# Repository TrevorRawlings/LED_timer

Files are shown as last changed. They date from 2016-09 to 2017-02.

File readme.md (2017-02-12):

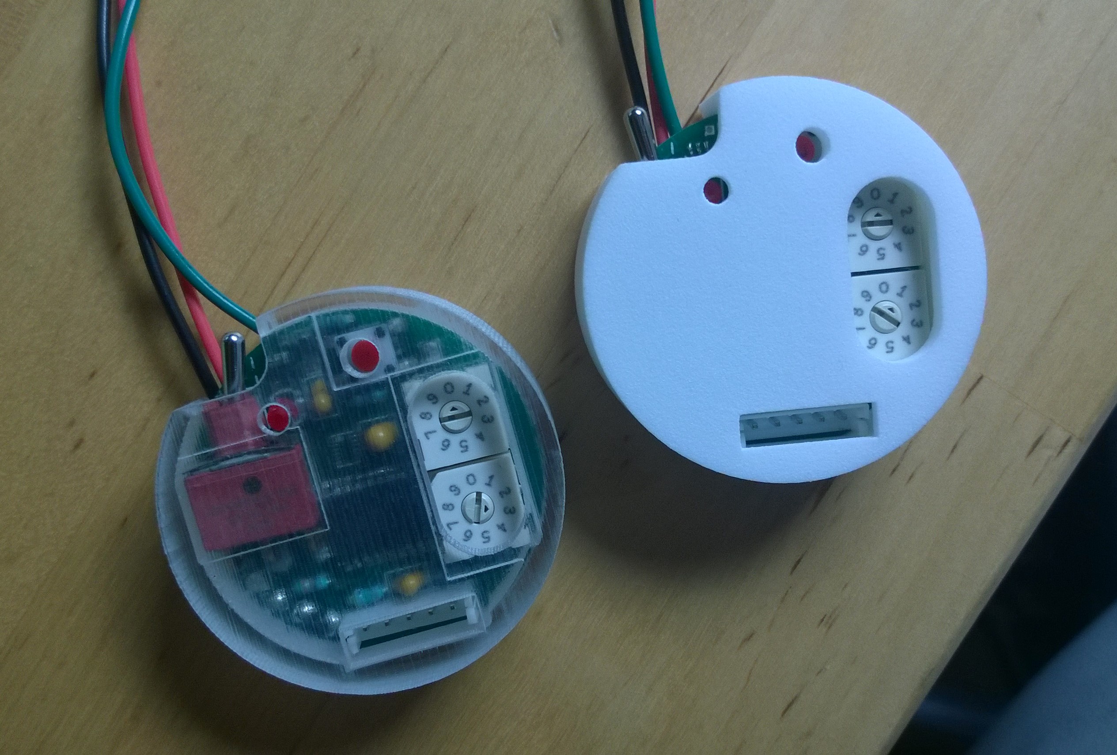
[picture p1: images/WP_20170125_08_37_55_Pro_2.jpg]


# Design Overview
## Mechanical

To fit within the waterproof housing the timer is limited to a 44mm diameter cylinder of height 15mm.

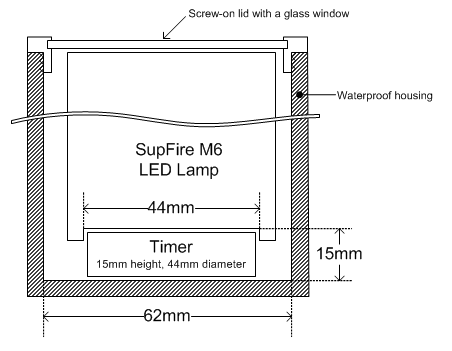
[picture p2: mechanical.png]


The case has been designed using [freeCad](https://www.freecadweb.org/). See the [Configuring FreeCad](#configuring-freecad) 
section below for help setting it up. 

The design files are in the `./freeCad` subdirectory and the finished designs have been 
uploaded to sculpteo ([sculpteo/case2-66](https://www.sculpteo.com/en/print/case2-66/AvhQv5jK) and [sculpteo/bottom-1007](https://www.sculpteo.com/en/print/bottom-1007/qzUkbDYg)).

## Electrical

The unit has a single 2 layer, 40mm diameter PCB.

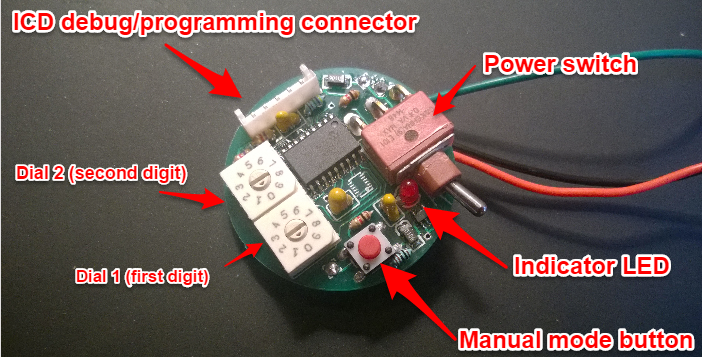
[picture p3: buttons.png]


The electrical design files are in the `./eagle` subfolder. The majority of the components have been sourced from [digiKey](http://www.digikey.com/). See [bill\_of\_materials.xlsx](bill_of_materials.xlsx) for details.

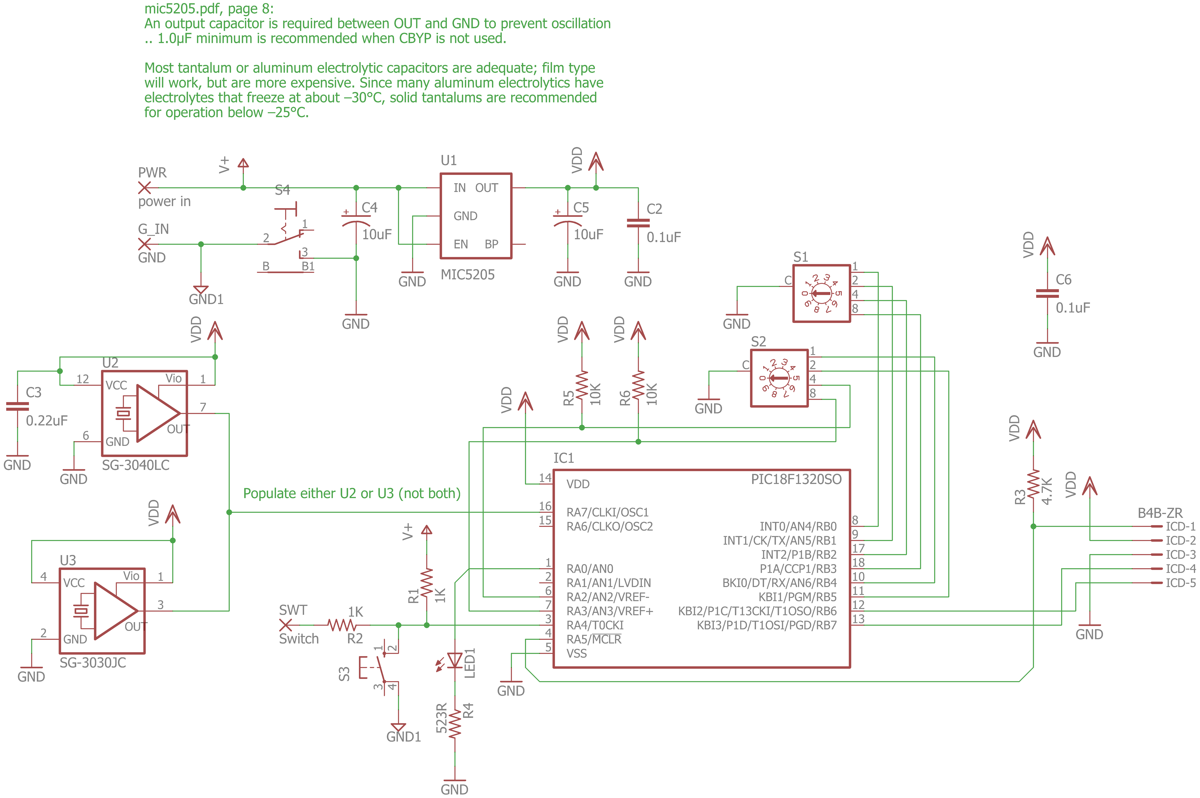
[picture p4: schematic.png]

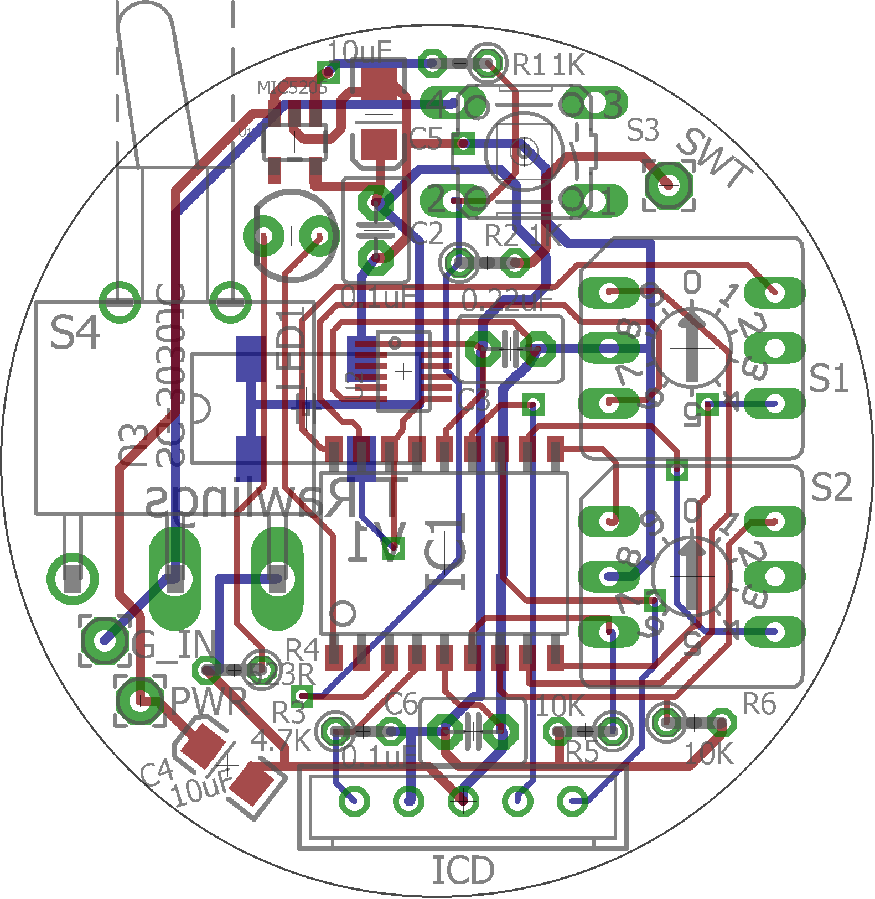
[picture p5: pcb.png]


### PCB Manufacture
The circuit boards have been manufactured using [PCBWay](http://www.pcbway.com/).  The steps required to gerber files required by PCBWay are documented in [a blog post](cam_processor/How to generate Gerber from Eagle-SOFTWARE - Share- Hacker - PCBWay.pdf)

TODO: Create a grunt task that automates the process.

Once the .zip archive containing the gerber files has been generated it needs to be uploaded to PCBWay.  The parameters used when submitting an order are [here](cam_processor/pcbway_order_parameters.pdf).

## Software

Software is in the `mplab\LED.X` subfolder.  

#Tools

1. [Cadsoft Eagle PCB Design](https://cadsoft.io/)

   To use the Grunt task the eagle binary will need to be in the [system path](http://www.computerhope.com/issues/ch000549.htm).  For me that meant adding `C:\EAGLE-7.6.0\bin` to the path.
   
1. [Microchip MPLAB X Integrated Development Envrionment (IDE)](http://www.microchip.com/mplab/mplab-x-ide)

1. [MPLAB ICD 3 In-Circuit Debugger](http://www.microchip.com/Developmenttools/ProductDetails.aspx?PartNO=DV164035)

1. [FreeCAD](http://www.freecadweb.org/)
1. [eaglepcb2freecad](https://sourceforge.net/projects/eaglepcb2freecad/?source=typ_redirect)

   A FreeCAD plugin that can import the PCB design from eagle and generate a 3D represenation of the PCB.
      1. Download the [FreeCAD plugin]( https://sourceforge.net/projects/eaglepcb2freecad/?source=typ_redirect)
      1. The .7zachive will need to be extracted. I used the linux tool [dtrx](https://brettcsmith.org/2007/dtrx/)
      1. Follow the instructions within the archive to install the plugin
	  1. eaglepcb2freecad's parts library will need to be configured.  See the [Configuring FreeCAD](#configuring-freecad) section below.

1. [Nodejs](https://nodejs.org/en/)
   Used to download the 3D CAD model libraries used by FreeCAD. 
   
   Download and run the installer. Then at the command prompt:
   ```
   npm install
   ```

2. [Grunt](http://gruntjs.com/getting-started#installing-the-cli)

   Used to automate some tasks.
   
   ```
   npm install -g grunt-cli
   ```

# Configuring FreeCAD

1. Configure eaglepcb2freecad. Open freeCAD and then from the top menu go Edit > Preferences.  In the window the opens select 'PCB' from the list on the left

  * Set the default board thickness to 1.6mm
  * Set the Parts:Paths to include the location of the [freecad_eagle_models](https://github.com/TrevorRawlings/freecad_eagle_models) and [electrical_components](https://github.com/TrevorRawlings/electrical_components) git repositories.  If you have run a `npm install` then two git repos will have been cloned into the node_modules subdirectory:
  
    <project_folder>\node_modules\electrical_components,
	<project_folder>\node_modules\freecad_eagle_models\models_1,
	<project_folder>\node_modules\freecad_eagle_models\models_2,
	<project_folder>\node_modules\freecad_eagle_models\models_3,
	<project_folder>\node_modules\freecad_eagle_models\models_4,
	
  * Import the parts database `eagle2FreecadPartsDb\freecad-pcb_copy.fpcb`
  
    Select 'Printed Circuit Board' `View > Workbench` menu and then click the Assign Models button on the PCB Settings tool bar (see the image below)
	
	
	
	In the window that openc click 'Import Database' from the menu on the left.
    	E:\projects\ALFA_LED\node_modules\electrical_components,E:\projects\ALFA_LED\node_modules\freecad_eagle_models\models_1,E:\projects\ALFA_LED\node_modules\freecad_eagle_models\models_2,E:\projects\ALFA_LED\node_modules\freecad_eagle_models\models_3,E:\projects\ALFA_LED\node_modules\freecad_eagle_models\models_4

	E:\freeCadModels\models_1,E:\freeCadModels\models_2,E:\freeCadModels\models_3,E:\freeCadModels\models_4,E:\freeCadModels\custom

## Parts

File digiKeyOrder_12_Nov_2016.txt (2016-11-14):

Index	Quantity	Part Number	Description	Customer Reference	Available Quantity	Backorder Quantity	Unit Price USD	Extended Price USD	
1	25	478-8275-1-ND	CAP TANT 10UF 20V 20% 1206	C4, C5	25	0	0.32440	8.11	
2	22	GH7252-ND	SWITCH ROTARY DIP BCD 100MA 50V	S1, S2	22	0	2.76200	60.76	
3	15	SER3697CT-ND	OSC XO 32.768KHZ CMOS SMD	U1	15	0	1.51400	22.71	
4	15	450-1804-ND	SWITCH TACTILE SPST-NO 0.05A 24V	S3	15	0	0.08600	1.29	
5	12	CKN1060-ND	SWITCH TOGGLE SPDT 0.4VA 20V	S4	12	0	4.98200	59.78	
6	50	RNF18FTD10K0CT-ND	RES 10K OHM 1/8W 1% AXIAL	ALT R3, R5, R6	50	0	0.03860	1.93	
7	50	RNF18FTD1K00CT-ND	RES 1K OHM 1/8W 1% AXIAL	R1, R2, R4	50	0	0.03860	1.93	
8	50	RNF18FTD4K75CT-ND	RES 4.75K OHM 1/8W 1% AXIAL	R3, R5, R6	50	0	0.03860	1.93	
9	15	576-1258-1-ND	IC REG LDO 3V 0.15A SOT23-5	U1	15	0	0.40000	6.00	
10	15	492-1785-ND	LED MT SELF RETAINING VERT		15	0	0.21400	3.21	
11	10	455-1614-ND	CONN HEADER EH TOP 5POS 2.5MM	ICD CONNECTOR	10	0	0.22300	2.23	
12	20	455-1042-1-ND	CONN TERM CRIMP EH 22-30AWG	ICD CONNECTOR	20	0	0.04900	0.98	
13	5	PIC18LF1320-I/SO-ND	IC MCU 8BIT 8KB FLASH 18SOIC	IC1	5	0	2.73000	13.65	
14	25	478-9315-ND	CAP TANT 0.1UF 50V 20% RADIAL	C2, C6	25	0	0.25200	6.30	
15	10	478-8818-ND	CAP TANT 0.22UF 50V 20% RADIAL	C3	10	0	0.29500	2.95	
16	10	TLLR4400-ND	LED RED DIFF 3.2MM ROUND T/H	LED1	10	0	0.35800	3.58	
17	10	SER3618CT-ND	OSC XO 32.768KHZ CMOS SMD	U3	10	0	1.46900	14.69	
18	50	RNF18FTD523RCT-ND	RES 523 OHM 1/8W 1% AXIAL	R4	50	0	0.03860	1.93	
						Subtotal	213.96
						Shipping	unknown
						Estimated Sales Tax	0.00
						Total	unknown

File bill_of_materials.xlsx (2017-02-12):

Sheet: Bill_of_materials
 |  | desc | manufacturer/part no | price | number per board | cost per board | source
 | RJ-11 | ICD debugger |  | 3.9 | 0 | 0 | digikey part number 553-2258-ND
 | JST-EH 5 pin | receptacle (housing) | EHR-5 | 0.1 | 0 |  | 455-1003-ND
 |  | socket |  | 0.24 | 1 |  | 455-1614-ND
 |  | crimp connectors | SEH-001T-P0.6 | 0.1 | 0 |  | 455-1042-1-ND
 | ICD |  |  | 200 | 0 | 0 | microchip.com
Microcontroller | PIC18LF1320-I/SO | SOIC, L = low voltage, I = temp range -40 to +85, 'T' would be better but is out of stock |  | 2.95 | 1 | 2.95 | microchip.com | http://www.microchip.com/wwwproducts/en/en010265
 | PIC18LF1320-I/P | PDIP |  | 2.86 | 0 | 0
 | PDIP socket |  |  | 2.03 | 0 | 0 | digikey: ED3047-5-ND
U1 | MIC5205 | IC REG LDO 3V 0.15A SOT23-5 |  | 0.4 | 1 | 0.4 | digiKey: 576-1258-1-ND
C4, C5 | Cap 10uF | ~~through hole~~ |  | ~~0.75~~ | ~~0~~ | ~~0~~ | digiKey: 732-6367-1-ND
 |  | surface mount, EIA 3216 (3.2mm x 1.6mm, height 1 mm) (http://www.digikey.com/product-search/en/capacitors/tantalum-capacitors/131082?k=Tantalum+capacitor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) |  | 0.53 | 2 | 1.06 | digiKey: 478-8275-1-ND (http://www.digikey.com/product-detail/en/avx-corporation/F931D106MAA/478-8275-1-ND/4005705) |  | https://en.wikipedia.org/wiki/Surface-mount_technology#Packages
C2, C6 | Cap 0.1 uF | tantalum through hole |  | 0.42 | 2 | 0.84 | digiKey: 478-9315-ND
C3 | Cap >0.1uF (0.22uF) | tantalum through hole |  | 0.42 | 1 | 0.42 | digiKey: 478-8818-ND
 |  | ~~surface mount~~ |  |  |  | 0
LED1 | LED: 1.9V, 2mA | ~~surface mount~~ |  | ~~0.51~~ | ~~0~~ | ~~0~~ | digiKey: 160-1909-1-ND
 |  | through hole, 3.2mm |  | 0.5 | 1 | 0.5 | digiKey: TLLR4400-ND
PCB |  | 40mm diameter |  | 8 | 1 | 8 | pcbway
S4 | toggle switch | DIP switch | Garyhill/76STD01T | 3.44 | 0 | 0 | digiKey: GH7722-ND | Not washable
 |  | through hole toggle switch (http://www.digikey.com/product-search/en/switches/toggle-switches/1114212?k=toggle+switch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) | E-Switch/100AWSP1T2B4M6RE (http://www.digikey.com/product-detail/en/e-switch/100AWSP1T2B4M6RE/EG2434-ND/378903) |  |  |  |  | min order 200
 |  |  | C&K Components/E101MD1ABE (http://www.digikey.com/product-detail/en/c-k-components/E101MD1ABE/CKN1060-ND/67008) | 5.23 | 1 | 5.23 | digiKey: CKN1060-ND
S1, S2 | rotary switch | BCD, 10 position rotary switch, 3-3, through hole (http://www.digikey.com/product-search/en/switches/dip-switches/1114203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) | E-Switch/RDMBR10P1T (http://www.digikey.com/en/supplier-centers/e/e-switch) | 2.28 | 0 | 0 | digiKey: EG4983-5-ND | min order 1050
 |  |  | Garyhill/EG4983-5-ND | 2.88 | 2 | 5.76 | digiKey: GH7252-ND
U2 | Oscillator | 32.768kHz, 12-SOJ package (http://www.digikey.com/product-search/en/crystals-and-oscillators/oscillators/852334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) | Epson/SG-3040LC 32.7680KB3: PURE SN (3.60mm x 2.40mm) | 1.58 | 1 | 1.58 | digiKey: SER3697CT-ND
 |  |  | Epson/SG-3030JC 32.7680 (10.50mm x 5.00mm) | 1.53 |  |  | difiKey: SER3618CT-ND (http://www.digikey.com/product-detail/en/epson/SG-3030JC-32.7680KB3:ROHS/SER3618CT-ND/1532566)
 |  |  | ~~Epson/SG-3030JF (7.10mm x 4.60mm)~~ | ~~1.75~~ | ~~0~~ |  | mouser: 732-SG3030JF32.7B3R, digiKey min quantity 250. (http://www.mouser.com/ProductDetail/Epson-Timing/SG-3030JF-327680KB3-ROHS/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)
S3 | push switch | FSM series, through hole push switch, red |  | 0.1 | 1 | 0.1 | digiKey: 450-1804-ND (http://www.digikey.com/product-search/en?mpart=1825910-7&vendor=450)
R1, R2 | 1K | 1/8 Watt |  |  | 2 | 0.1
R3, R5, R6 | 4.7K | 1/8 Watt |  |  | 3 | 0.1
 | 10K | 1/8 Watt
R4 | 523R | 1/8 Watt |  |  | 1 | 0.1
Case (top) |  |  |  | 10.96 | 1 | 10.96 | https://www.sculpteo.com/en/print/case2-66/AvhQv5jK?uuid=f9ZfCk0V1UJiLpptjkHjRe
Case(bottom) |  |  |  | 8.87 | 1 | 8.87 | https://www.sculpteo.com/en/print/bottom-989/SD7MaZaD
 |  |  |  |  | total: | 46.97

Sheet: order_13_Nov
 |  | desc | manufacturer/part no | price | number per board | number for 10 boards | in stock | num to order | unit cost | line price | line | source
 | RJ-11 | ICD debugger |  | 3.9 | 0 |  |  |  | 0 |  |  | digikey part number 553-2258-ND
 | JST-EH 5 pin |  | EHR-5 | 0.1 | 0 |  |  |  |  |  |  | 455-1003-ND
 |  | socket |  | 0.24 | 1 | 10 | 2 | 8 | 0.24 | 1.92 | 11 | 455-1614-ND
 |  | crimp connectors | SEH-001T-P0.6 | 0.1 | 0 |  | 5 | 10 | 0.1 | 1 | 12 | 455-1042-1-ND
 | ICD |  |  | 200 | 0 |  |  |  | 0 |  |  | microchip.com
IC1 | PIC18LF1320-I/SO | SOIC, L = low voltage, I = temp range -40 to +85, 'T' would be better but is out of stock |  | 2.95 | 1 | 10 | 8 | 4 | 2.95 | 11.8 | 13 | digiKey: PIC18LF1320-I/SO-ND, microchip.com | http://www.microchip.com/wwwproducts/en/en010265
 | PIC18LF1320-I/P | PDIP |  | 2.86 | 0 |  |  |  | 0
 | PDIP socket |  |  | 2.03 | 0 |  |  |  | 0 |  |  | digikey: ED3047-5-ND
U1 | MIC5205 | IC REG LDO 3V 0.15A SOT23-5 |  | 0.4 | 1 | 10 | 0 | 15 | 0.4 | 6 | 9 | digiKey: 576-1258-1-ND
C4, C5 | Cap 10uF | ~~through hole~~ |  | ~~0.75~~ | ~~0~~ |  |  |  | ~~0~~ |  |  | digiKey: 732-6367-1-ND
 |  | surface mount, EIA 3216 (3.2mm x 1.6mm, height 1 mm) (http://www.digikey.com/product-search/en/capacitors/tantalum-capacitors/131082?k=Tantalum+capacitor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) |  | 0.53 | 2 | 20 | 0 | 25 | 1.06 | 26.5 | 1 | digiKey: 478-8275-1-ND (http://www.digikey.com/product-detail/en/avx-corporation/F931D106MAA/478-8275-1-ND/4005705) |  | https://en.wikipedia.org/wiki/Surface-mount_technology#Packages
C2, C6 | Cap 0.1 uF | tantalum through hole |  | 0.42 | 2 | 20 | 8 | 25 | 0.42 | 10.5 | 14 | digiKey: 478-9315-ND
C3 | Cap >0.1uF (0.22uF) | tantalum through hole |  | 0.42 | 1 | 10 | 2 | 10 | 0.42 | 4.2 | 15 | digiKey: 478-8818-ND
 |  | ~~surface mount~~ |  |  |  |  |  |  | 0
LED1 | LED: 1.9V, 2mA | ~~surface mount~~ |  | ~~0.51~~ | ~~0~~ |  |  |  | ~~0~~ |  |  | digiKey: 160-1909-1-ND
 |  | through hole, 3.2mm |  | 0.5 | 1 | 10 | 7 | 10 | 0.5 | 5 | 16 | digiKey: TLLR4400-ND
PCB |  | 40mm diameter |  | 8 | 1 |  |  |  | 8 |  |  | pcbway
S4 | toggle switch | DIP switch | Garyhill/76STD01T | 3.44 | 0 |  |  |  | 0 |  |  | digiKey: GH7722-ND | Not washable
 |  | through hole toggle switch (http://www.digikey.com/product-search/en/switches/toggle-switches/1114212?k=toggle+switch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) | E-Switch/100AWSP1T2B4M6RE (http://www.digikey.com/product-detail/en/e-switch/100AWSP1T2B4M6RE/EG2434-ND/378903) |  |  |  |  |  |  |  |  |  | min order 200
 |  |  | C&K Components/E101MD1ABE (http://www.digikey.com/product-detail/en/c-k-components/E101MD1ABE/CKN1060-ND/67008) | 5.23 | 1 | 10 | 1 | 12 | 5.23 | 62.76 | 5 | digiKey: CKN1060-ND
S1, S2 | rotary switch | BCD, 10 position rotary switch, 3-3, through hole (http://www.digikey.com/product-search/en/switches/dip-switches/1114203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) | E-Switch/RDMBR10P1T (http://www.digikey.com/en/supplier-centers/e/e-switch) | 2.28 | 0 |  |  |  | 0 |  |  | digiKey: EG4983-5-ND | min order 1050
 |  |  | Garyhill/EG4983-5-ND | 2.88 | 2 | 20 | 0 | 22 | 5.76 | 126.72 | 2 | digiKey: GH7252-ND
U2 | Oscillator | 32.768kHz, 12-SOJ package (http://www.digikey.com/product-search/en/crystals-and-oscillators/oscillators/852334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) | Epson/SG-3040LC 32.7680KB3: PURE SN (3.60mm x 2.40mm) | 1.58 | 1 | 10 | 3 | 15 | 1.58 | 23.7 | 3 | digiKey: SER3697CT-ND
 |  |  | Epson/SG-3030JC 32.7680 (10.50mm x 5.00mm) | 1.53 |  | 10 | 3 | 10 |  |  | 17 | digiKey: SER3618CT-ND (http://www.digikey.com/product-detail/en/epson/SG-3030JC-32.7680KB3:ROHS/SER3618CT-ND/1532566)
 |  |  | ~~Epson/SG-3030JF (7.10mm x 4.60mm)~~ | ~~1.75~~ | ~~0~~ |  |  |  |  |  |  | mouser: 732-SG3030JF32.7B3R, digiKey min quantity 250. (http://www.mouser.com/ProductDetail/Epson-Timing/SG-3030JF-327680KB3-ROHS/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)
S3 | push switch | FSM series, through hole push switch, red |  | 0.1 | 1 | 10 | 2 | 15 | 0.1 | 1.5 | 4 | digiKey: 450-1804-ND (http://www.digikey.com/product-search/en?mpart=1825910-7&vendor=450)
R1, R2 | 1K | 1/8 Watt |  |  | 2 | 20 | 6 | 14 | 0.1 | 1.4 | 7 | digiKey: 18FTD1K00CT-ND
R3, R5, R6 | 4.7K | 1/8 Watt |  |  | 3 | 30 | 6 | 24 | 0.1 | 2.4 | 8 | digiKey: RNF 18FTD4K75CT-ND
 | 10K | 1/8 Watt |  |  |  | 30 | 0 | 30 | 0.1 | 3 | 6 | digiKey: RNF18FTD10K0CT-ND (http://www.digikey.com/product-search/en?keywords=RNF18FTD10K0CT-ND)
R4 | 523R | 1/8 Watt |  |  | 1 | 10 | 0 | 10 | 0.1 | 1 | 18 | digiKey: RNF18FTD523RCT-ND
 |  |  |  |  | total: |  |  |  |  | 289.4

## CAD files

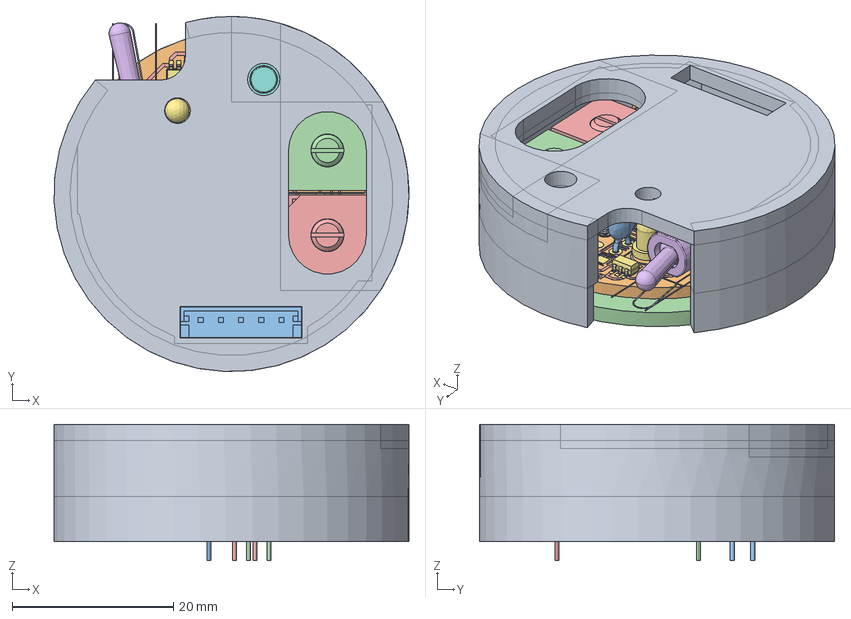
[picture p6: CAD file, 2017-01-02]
freeCad/assembly.FCStd
44.0 x 44.0 x 16.9 mm
case_01
Board001
C2001
C3001
C6001
IC1001
LED1001
R1001
R2001
R3001
R4001
S1001
S2001
S4001
U1001
S3001
R5001
R6001
ICD001
U3
Top_1001
Bottom_16001
tPad_17001
bPad_18001
tPlace_21001
bPlace_22001
tDocu_51001
bottom_01

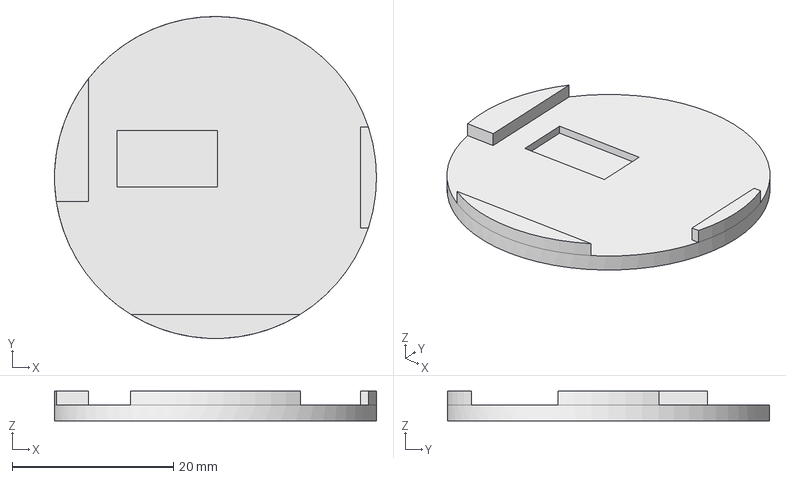
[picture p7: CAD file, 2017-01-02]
freeCad/bottom.step
40.0 x 40.0 x 3.70 mm

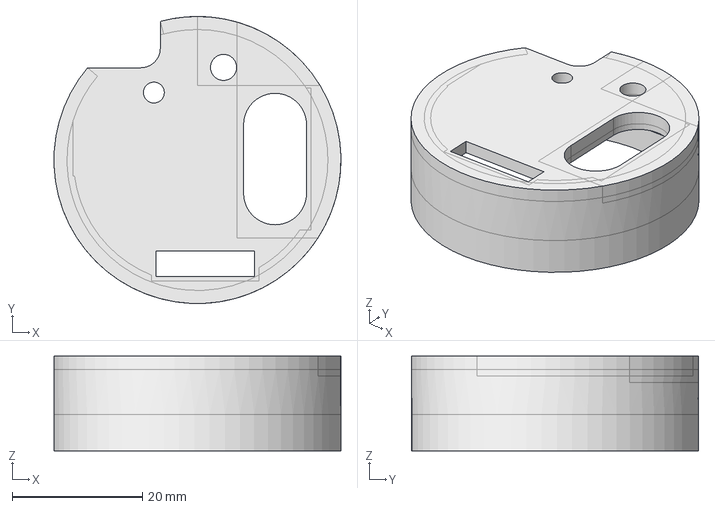
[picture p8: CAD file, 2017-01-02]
freeCad/case.step
44.0 x 44.0 x 14.5 mm

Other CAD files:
freeCad/bottom.FCStd
freeCad/bottom.stl
freeCad/case.FCStd
freeCad/case.stl

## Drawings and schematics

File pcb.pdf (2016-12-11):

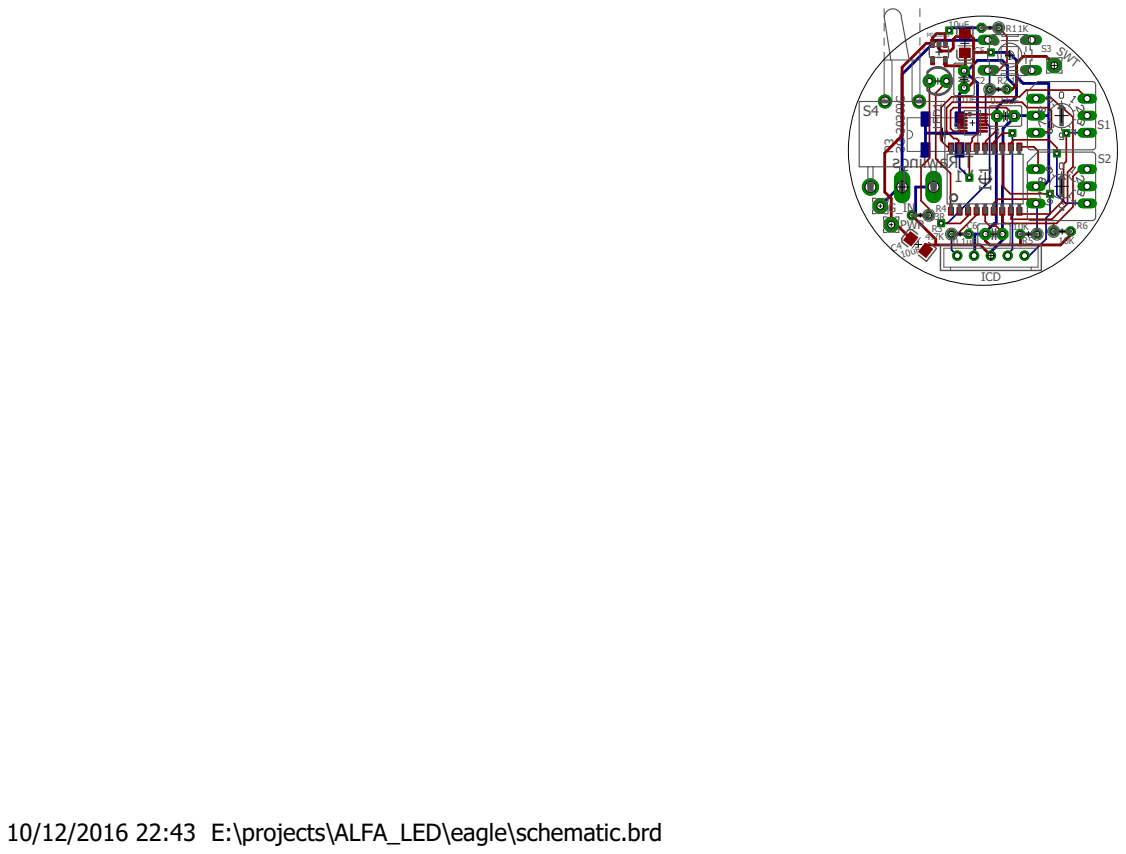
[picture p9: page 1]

10/12/2016 22:43 E:\projects\ALFA_LED\eagle\schematic.brd

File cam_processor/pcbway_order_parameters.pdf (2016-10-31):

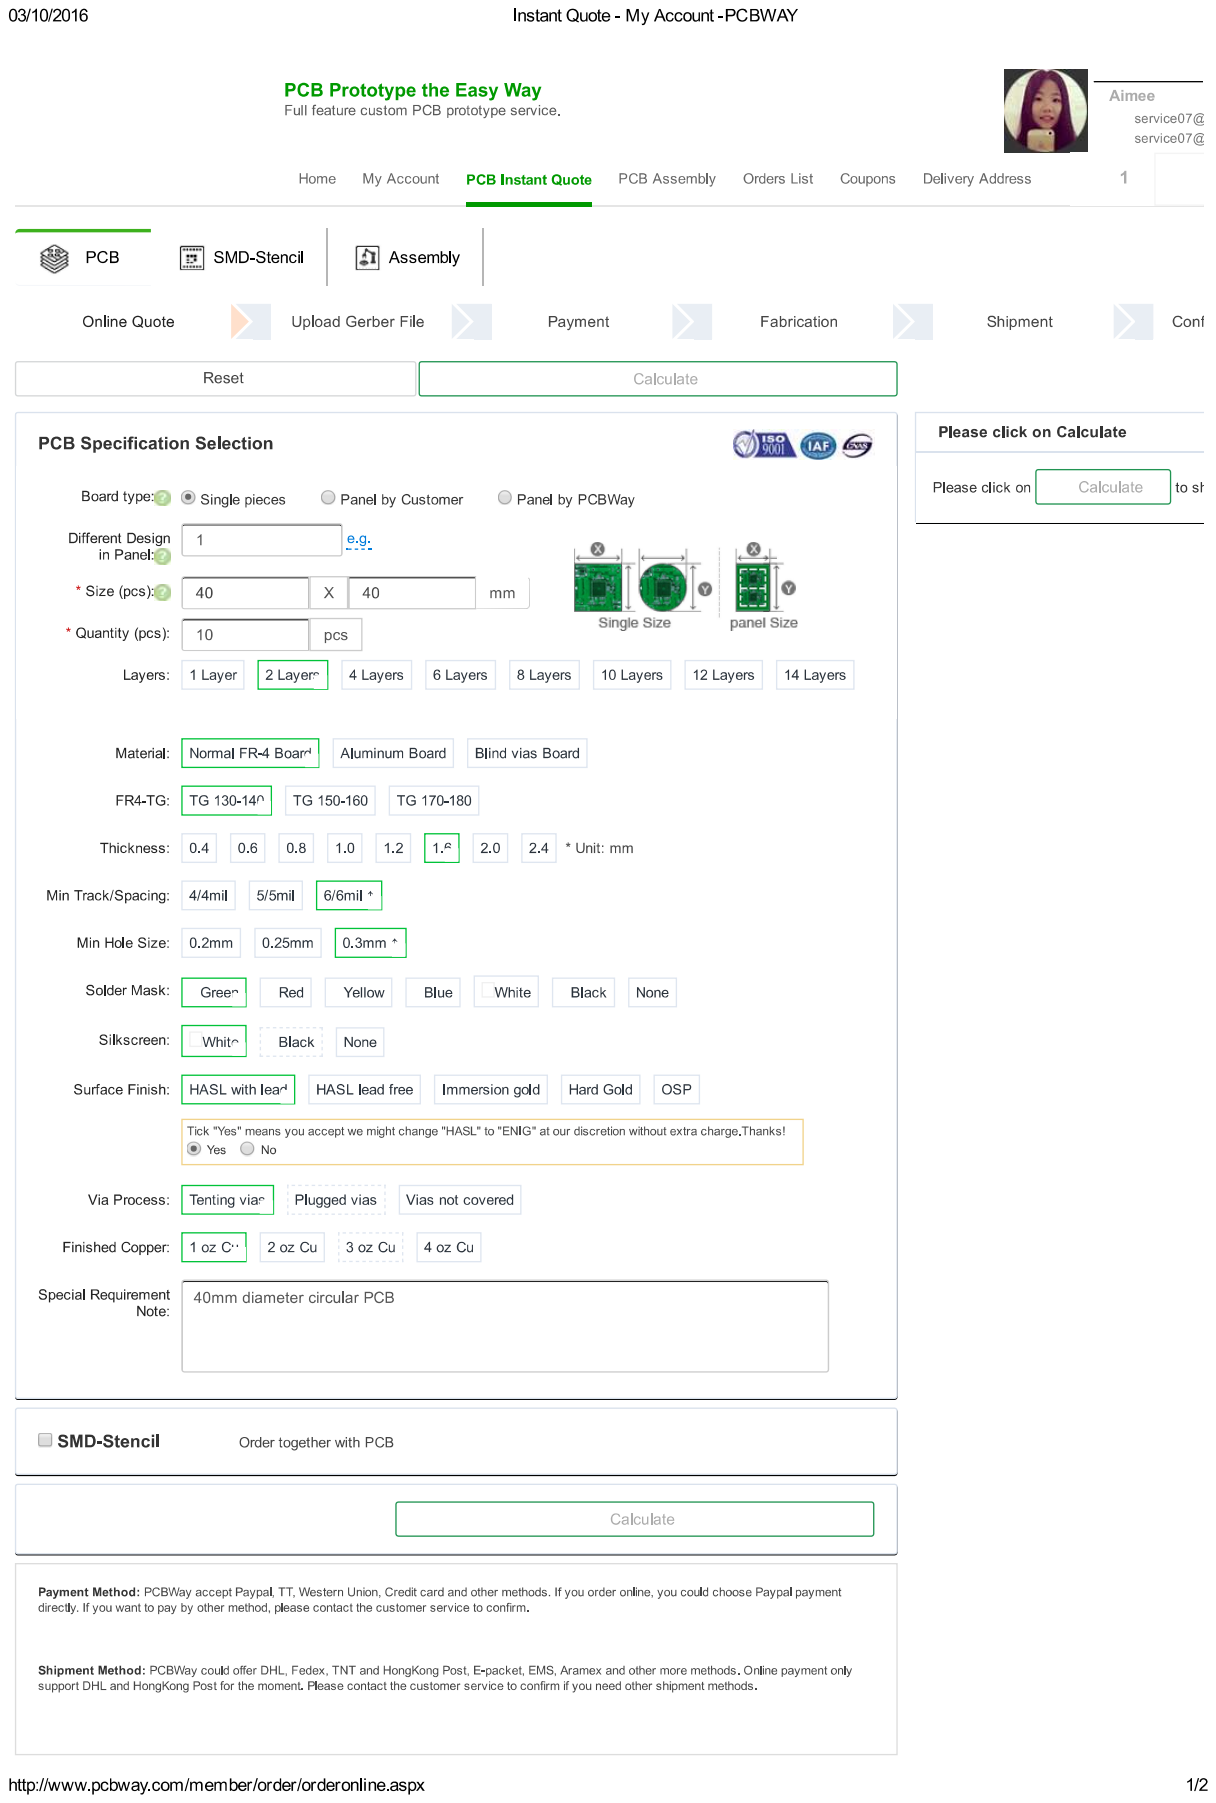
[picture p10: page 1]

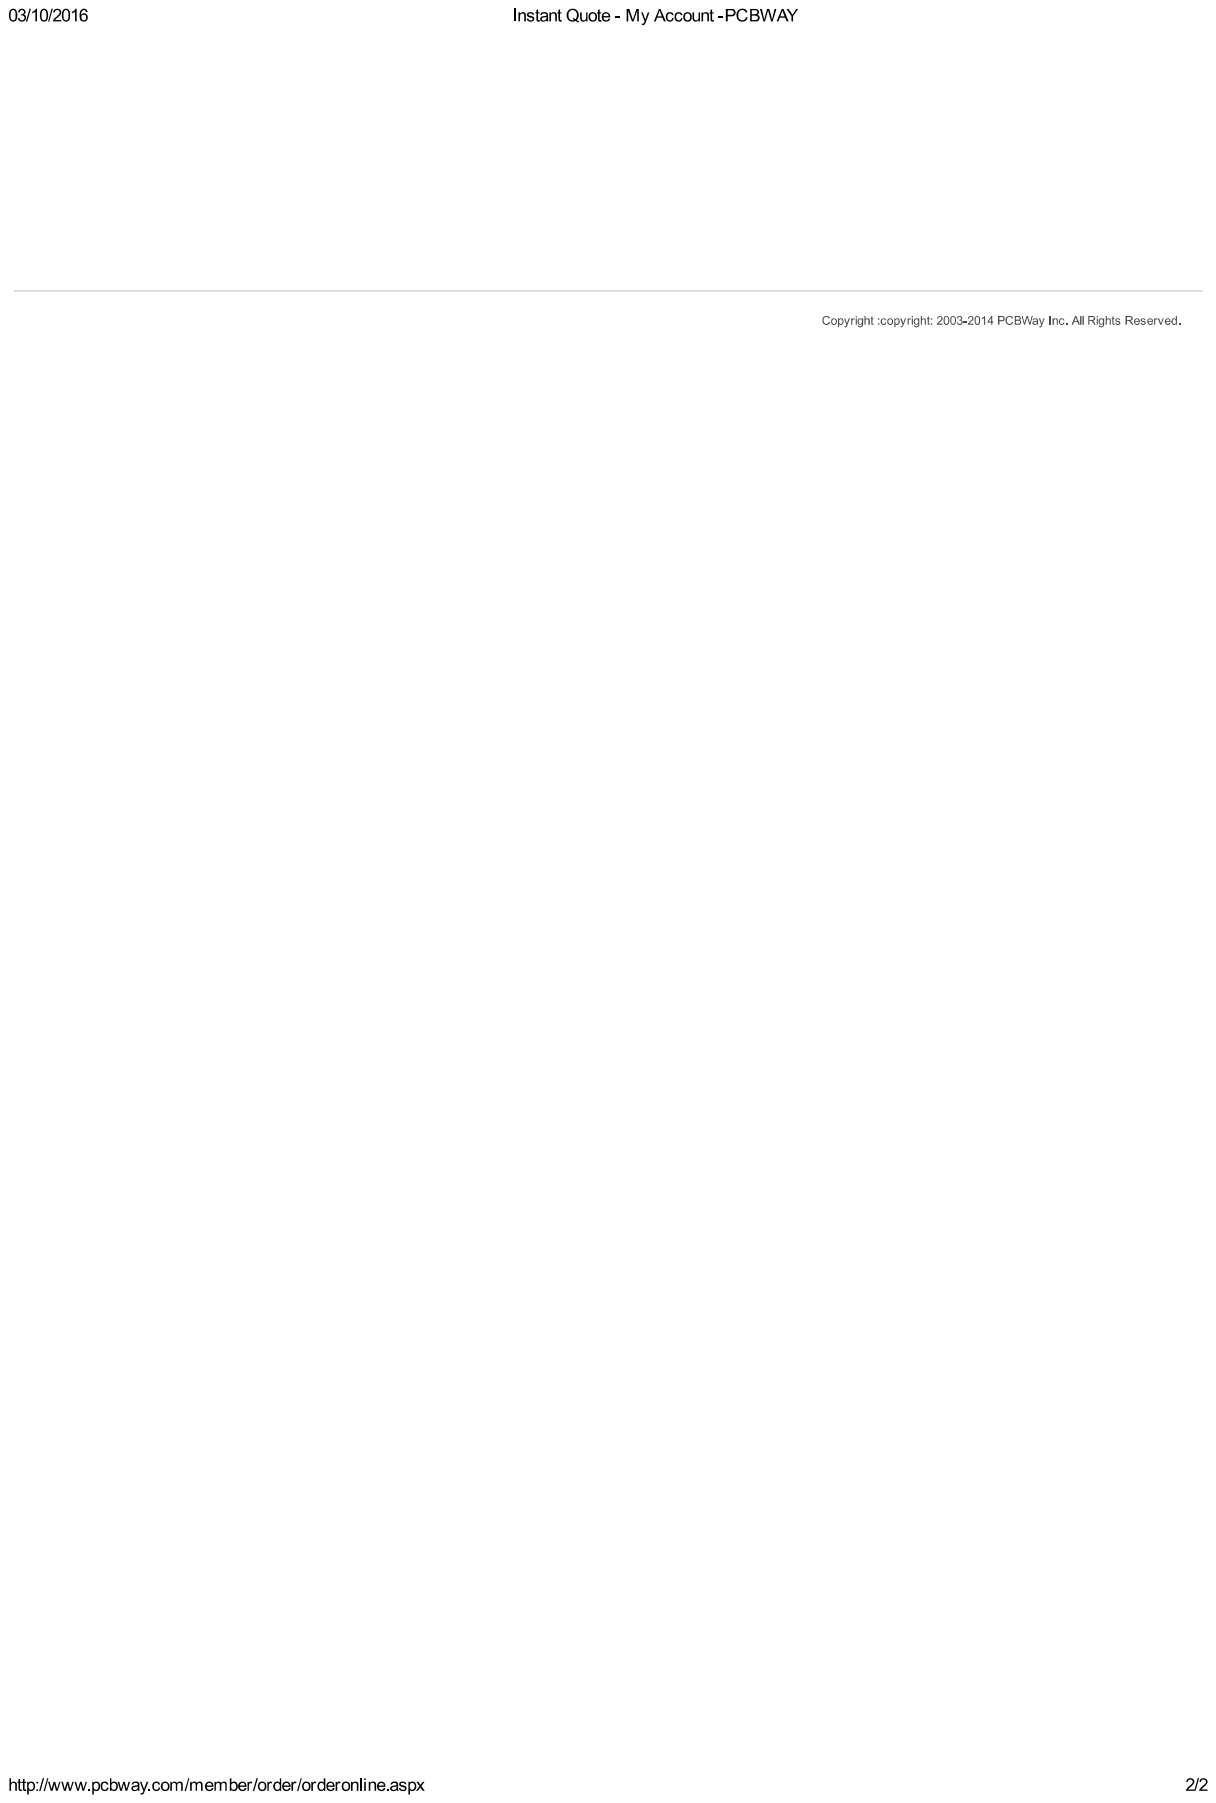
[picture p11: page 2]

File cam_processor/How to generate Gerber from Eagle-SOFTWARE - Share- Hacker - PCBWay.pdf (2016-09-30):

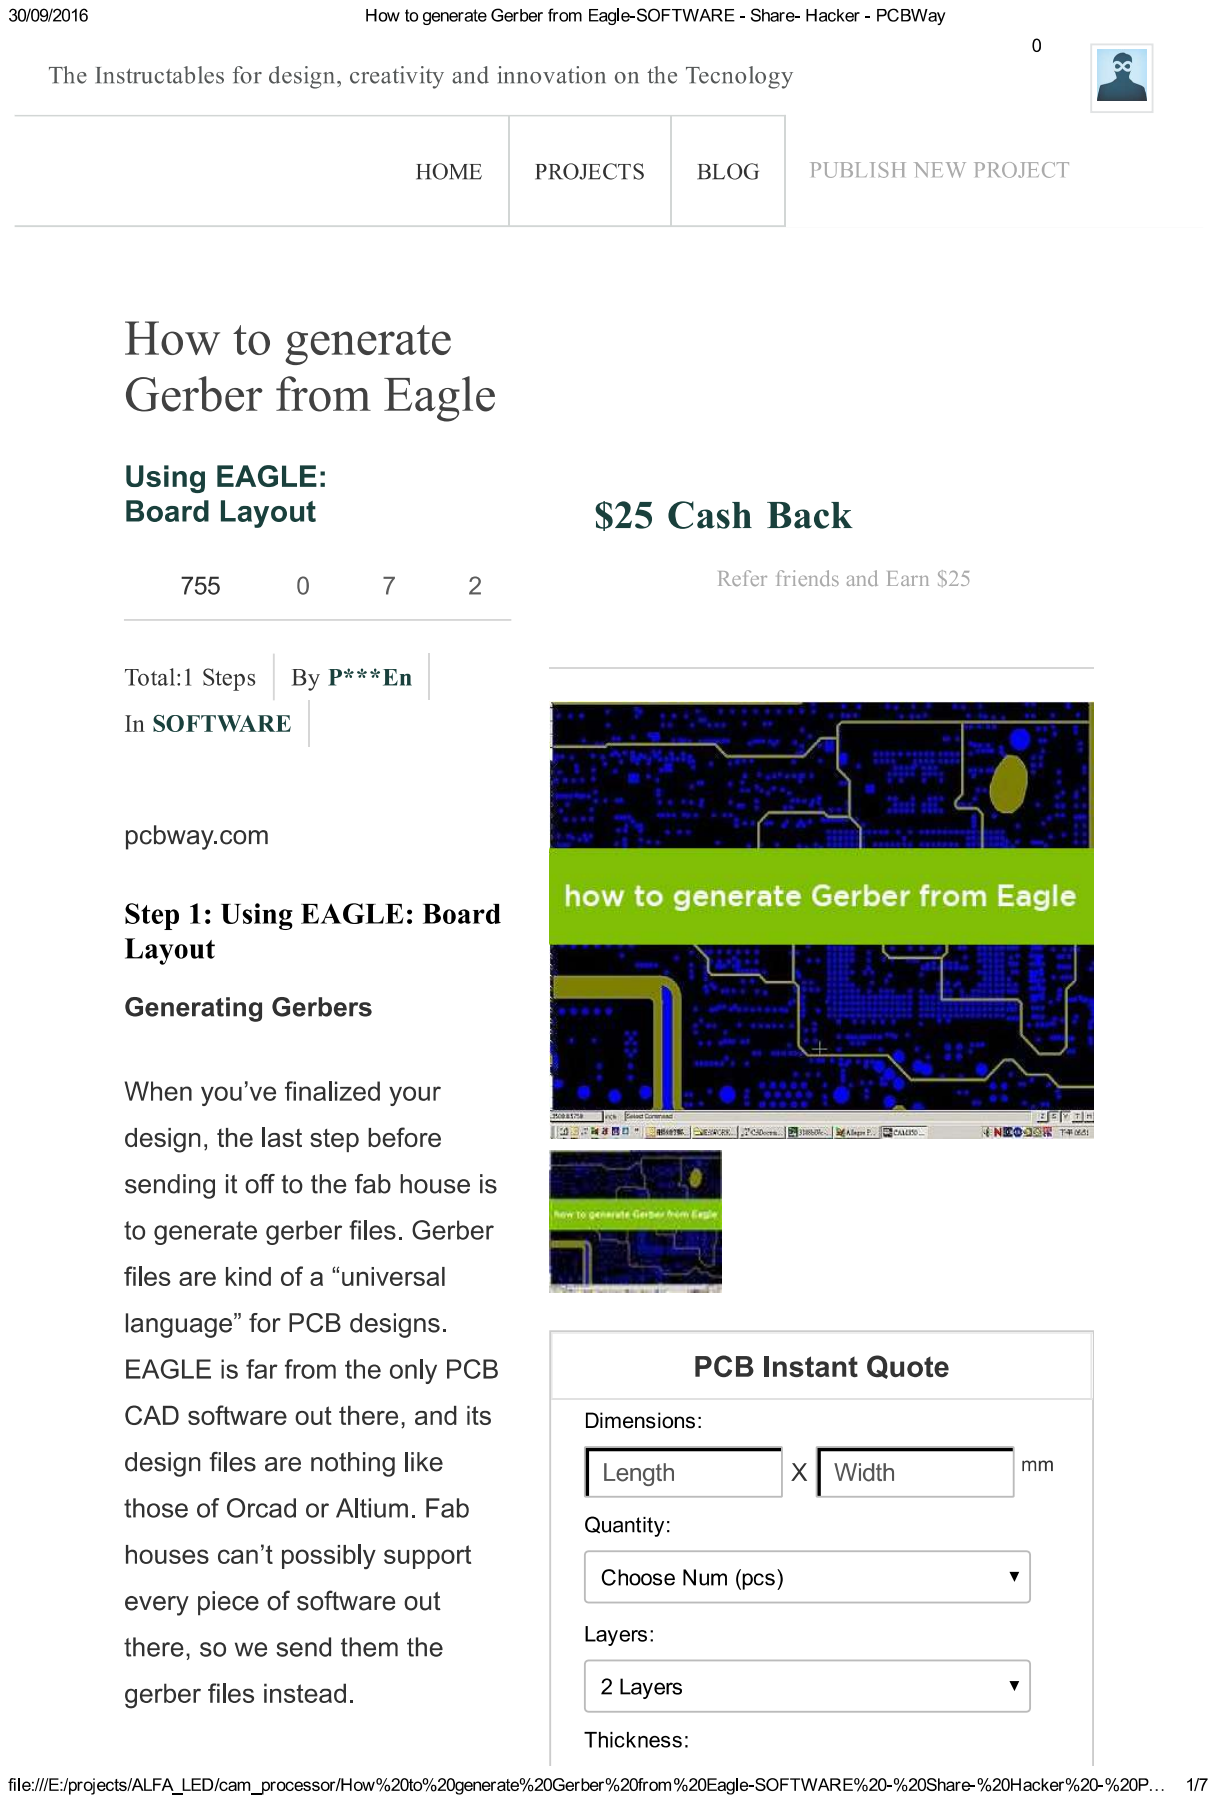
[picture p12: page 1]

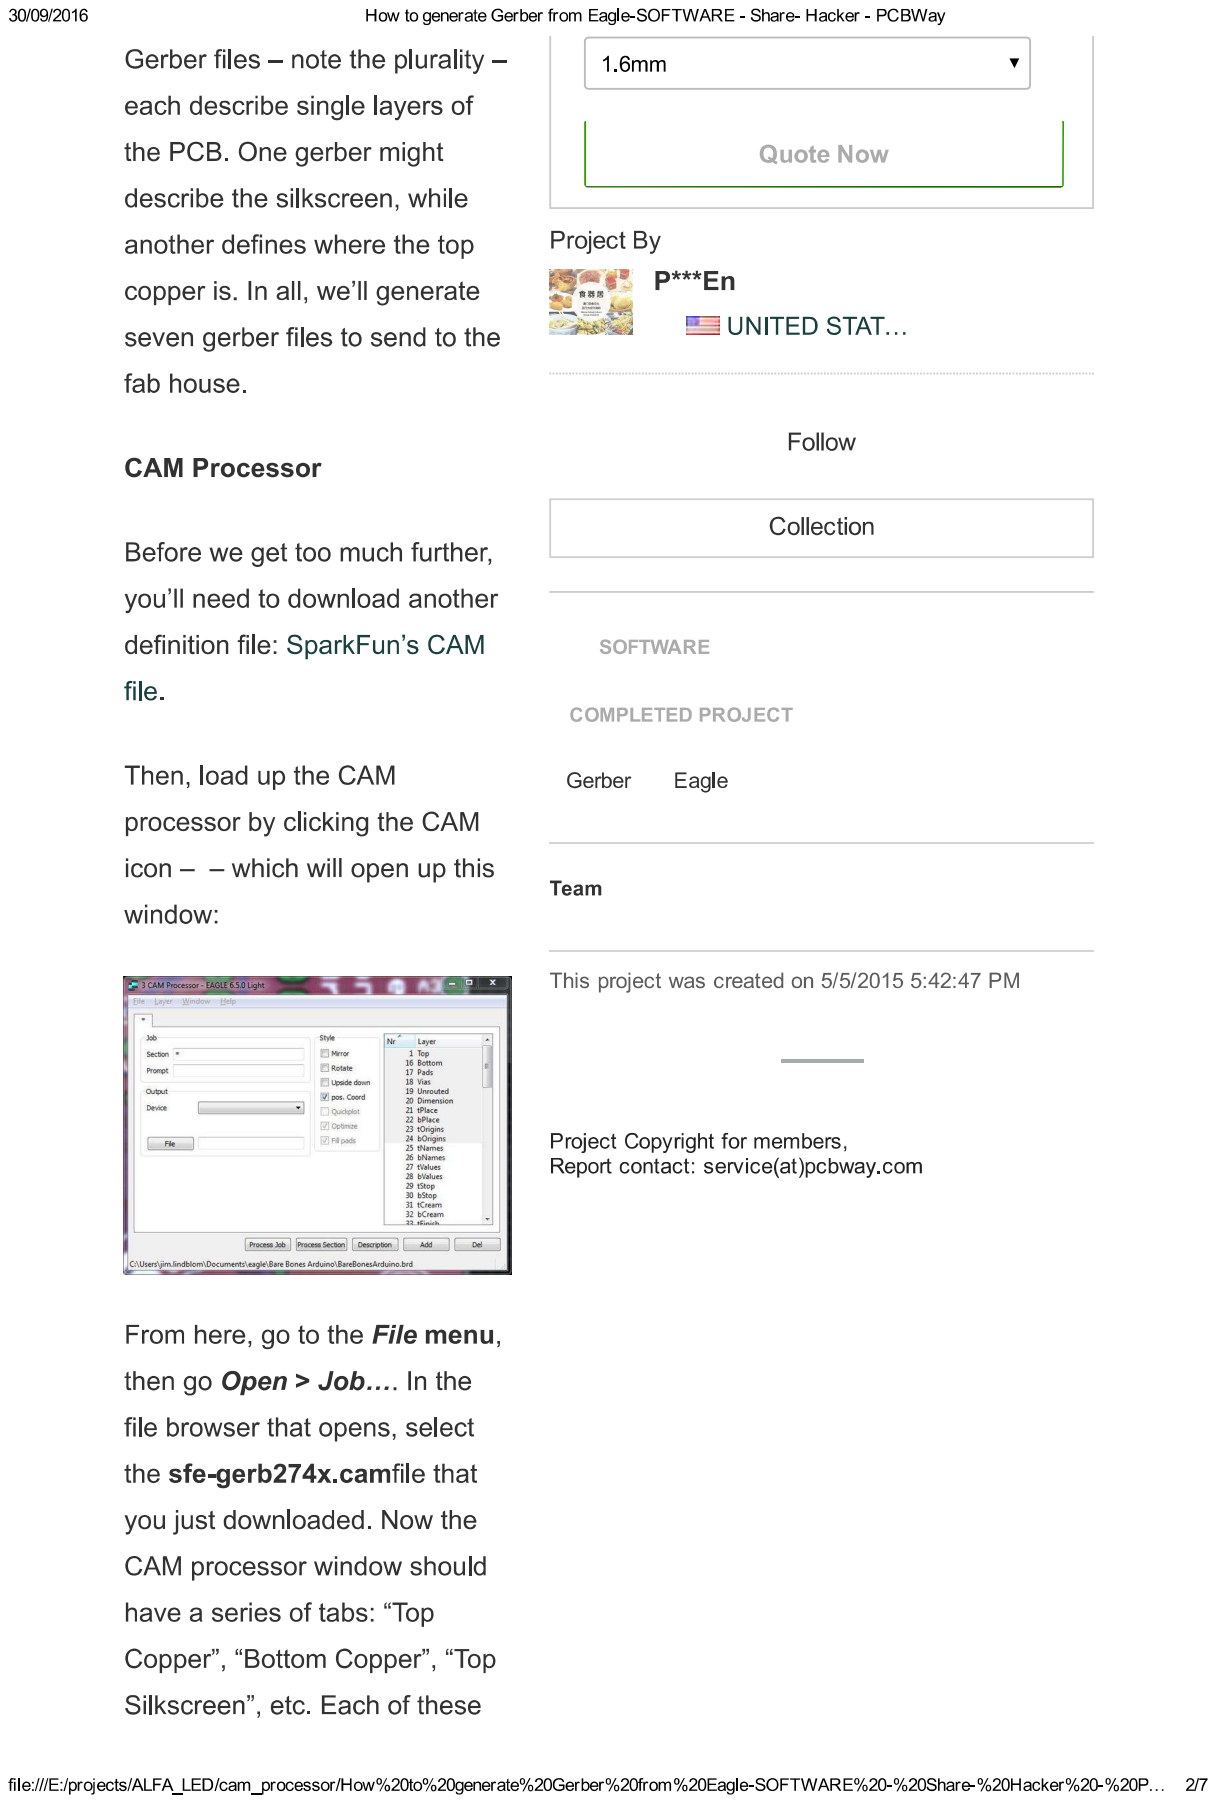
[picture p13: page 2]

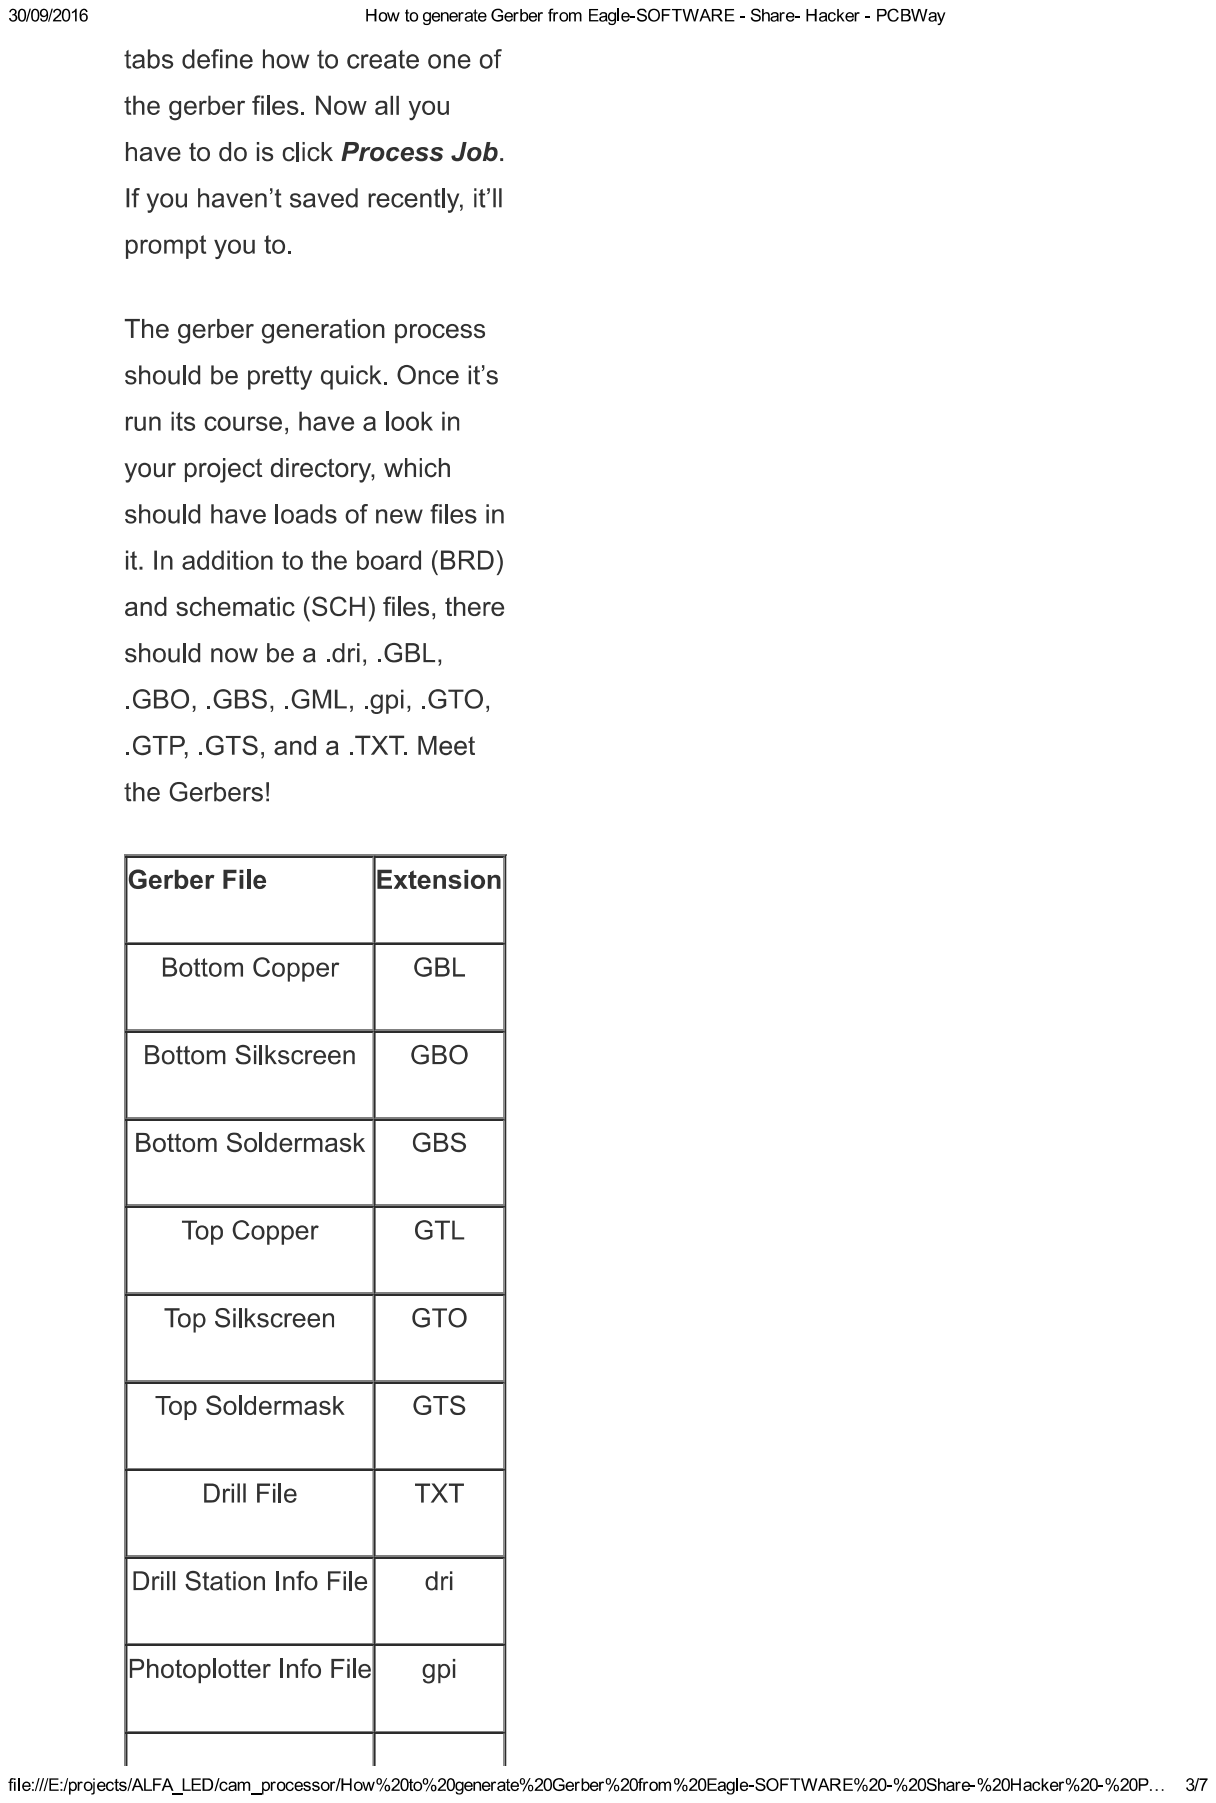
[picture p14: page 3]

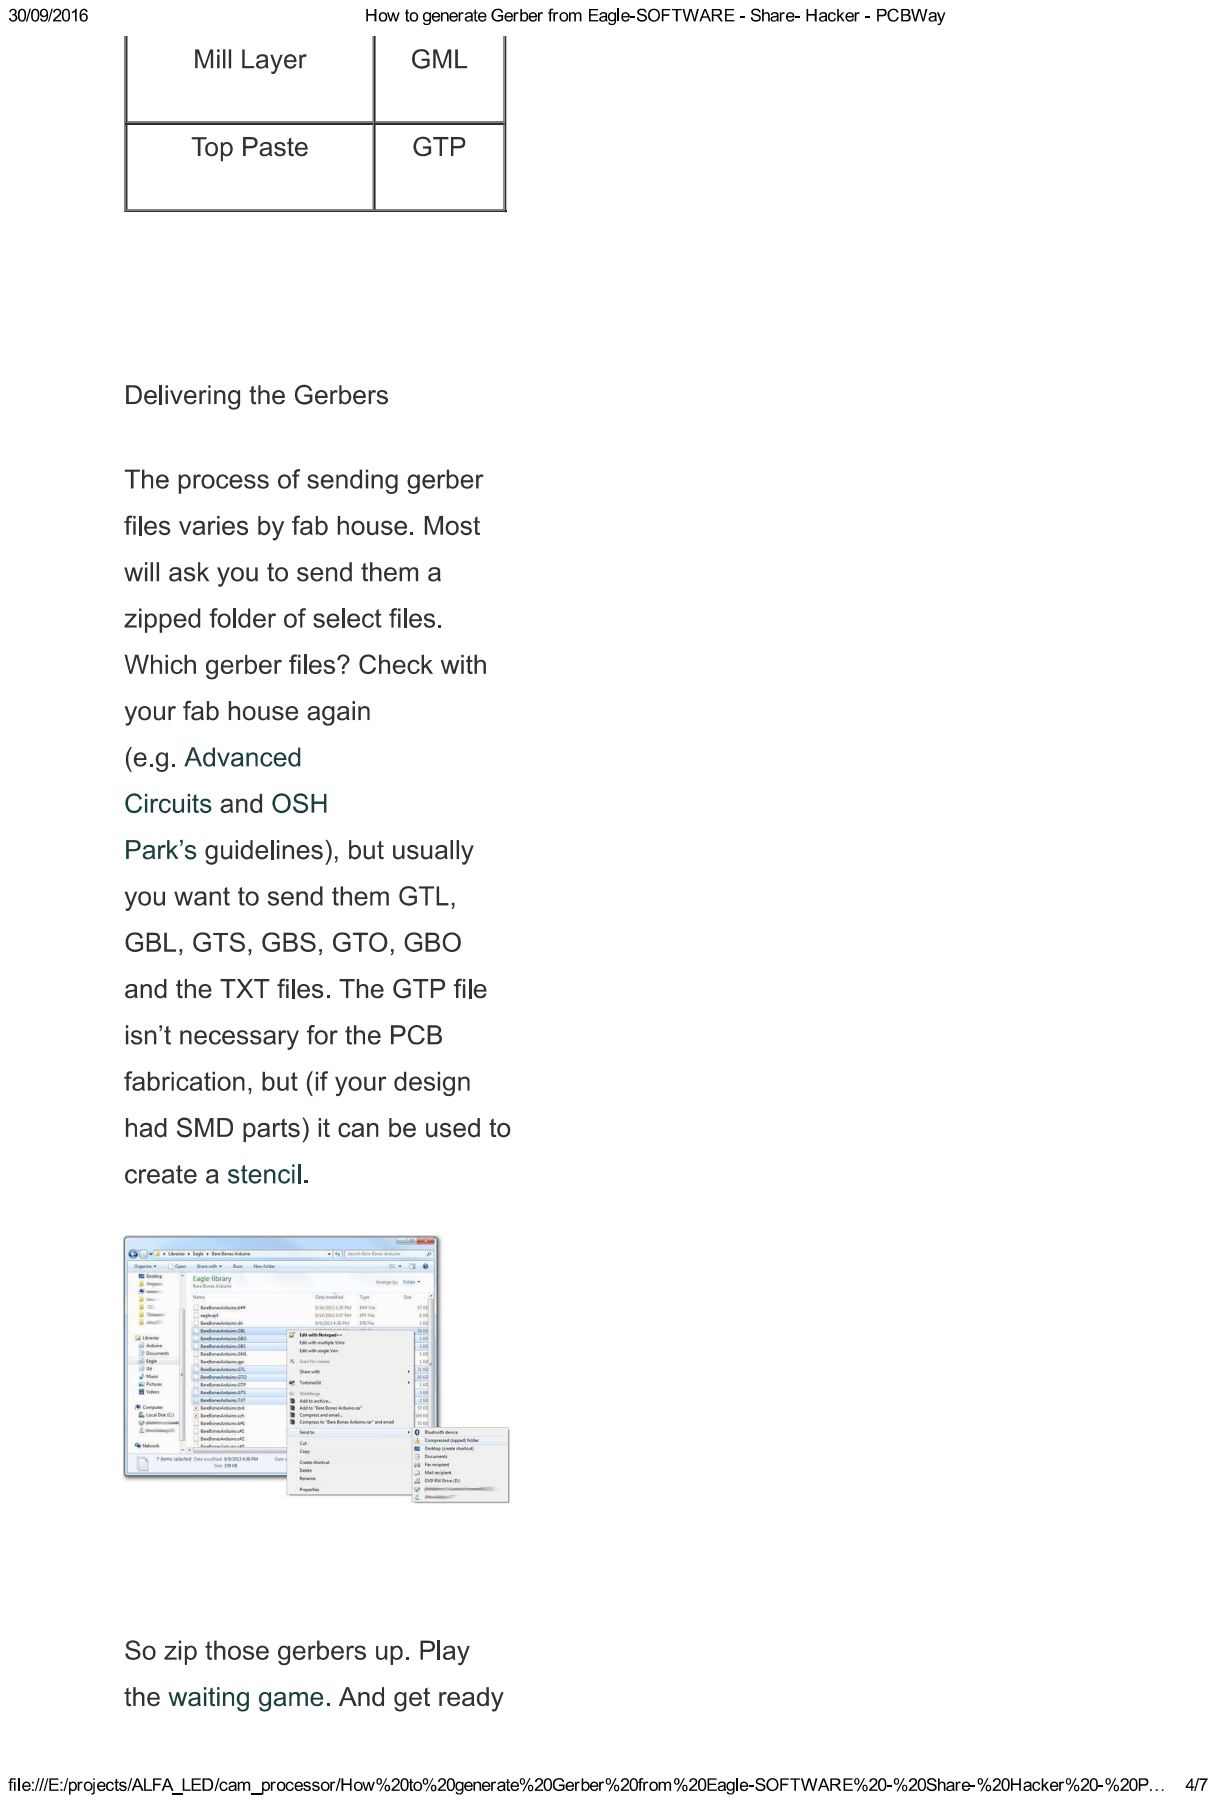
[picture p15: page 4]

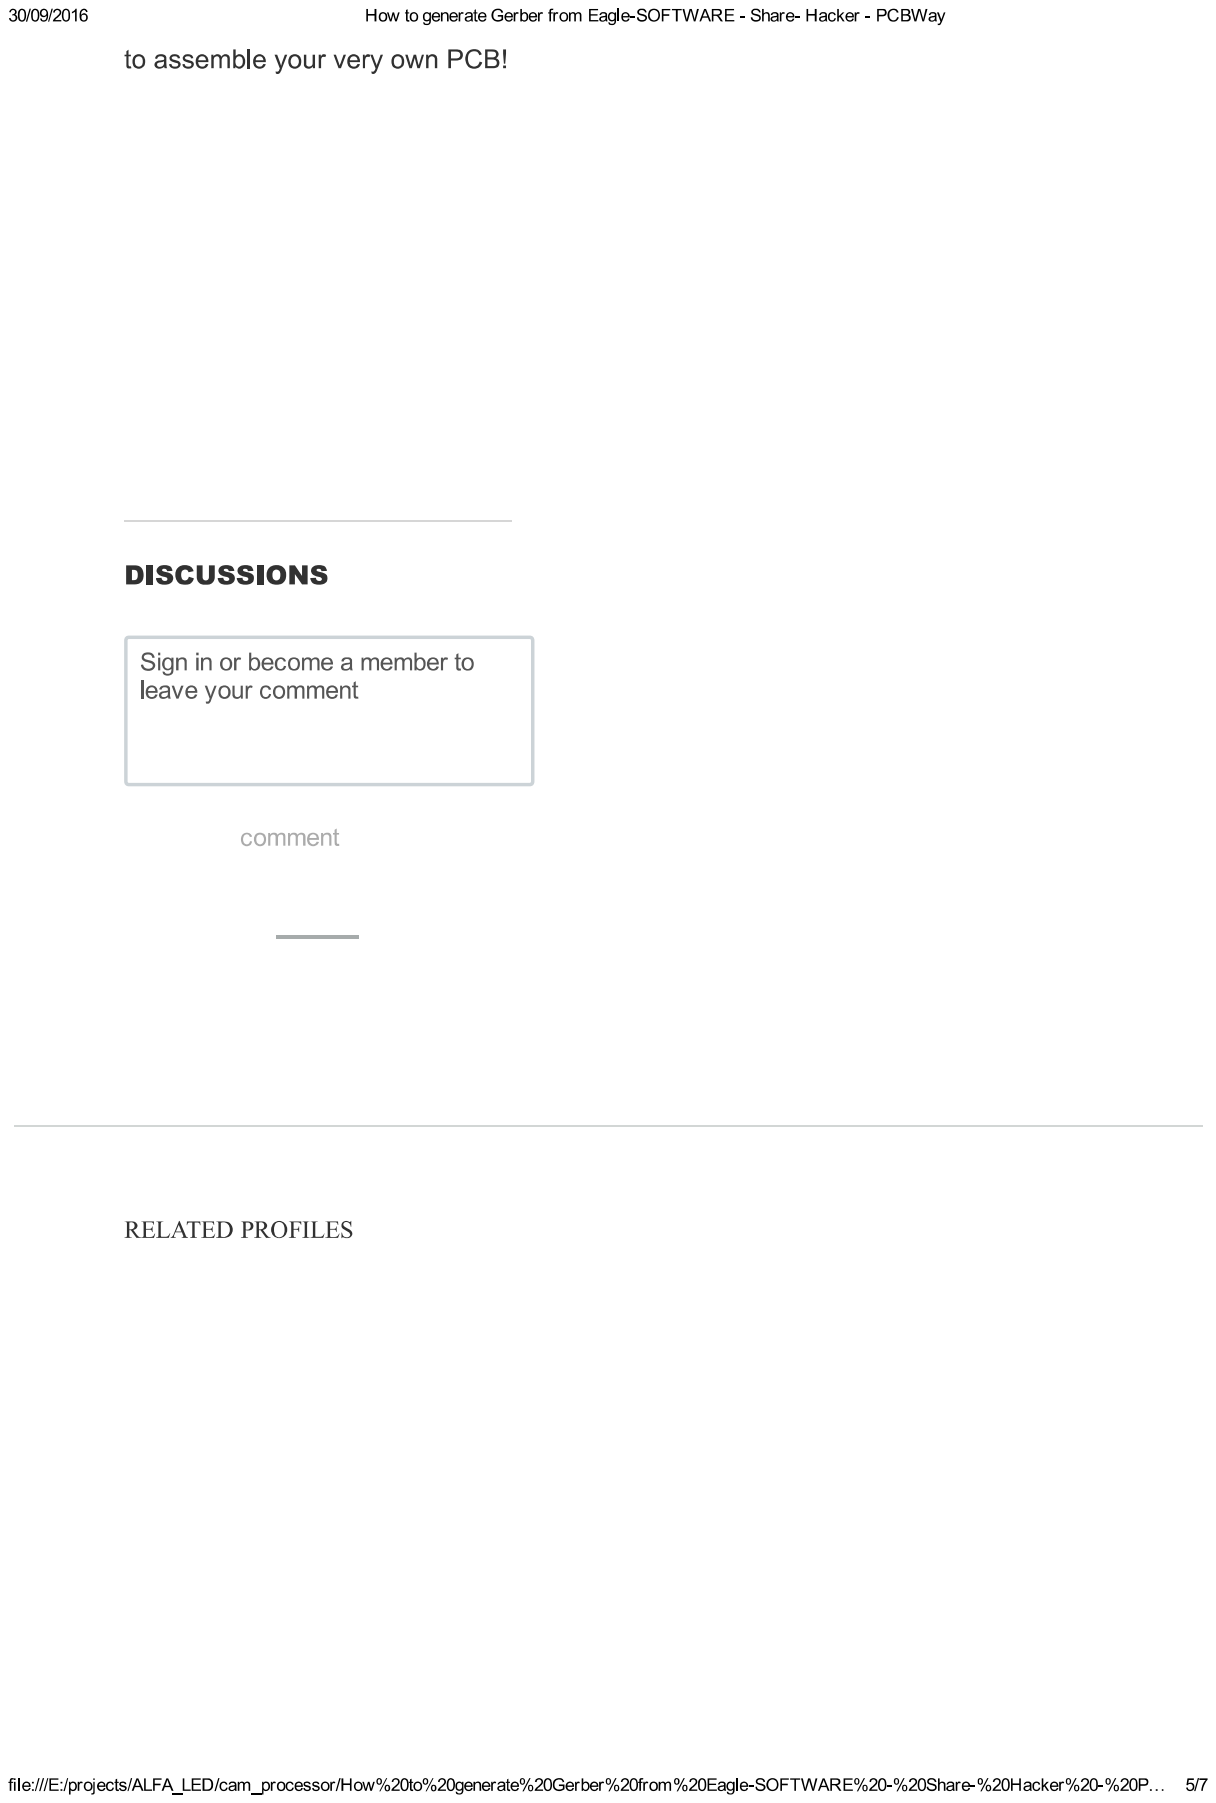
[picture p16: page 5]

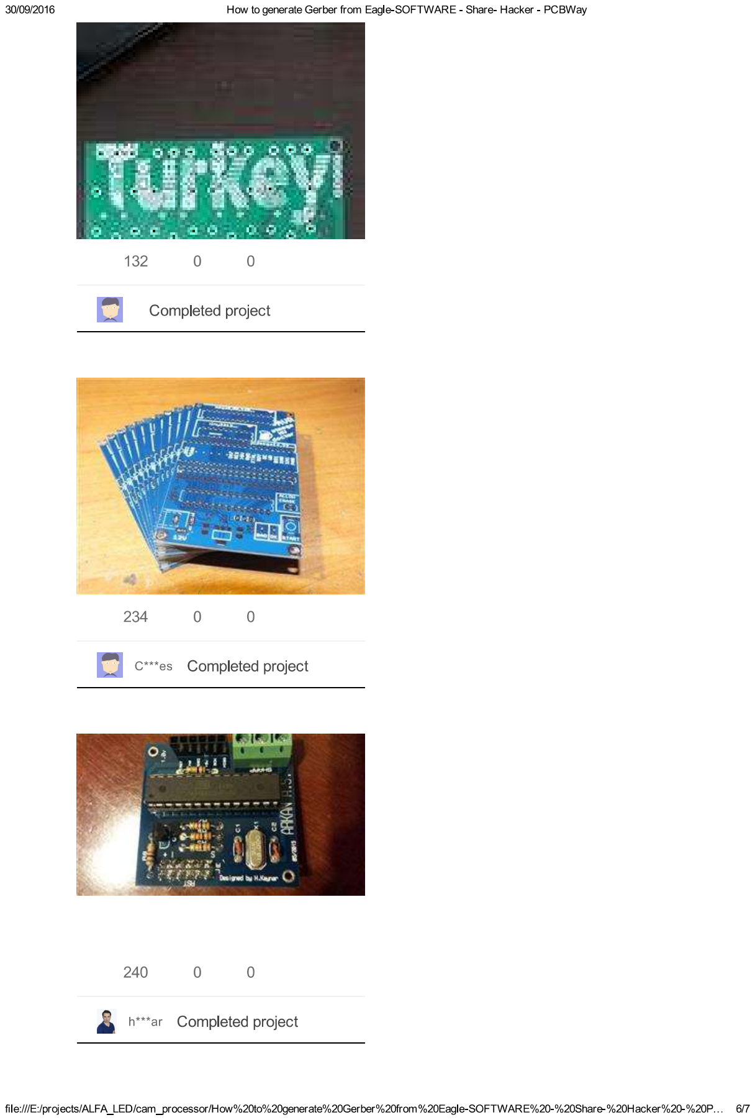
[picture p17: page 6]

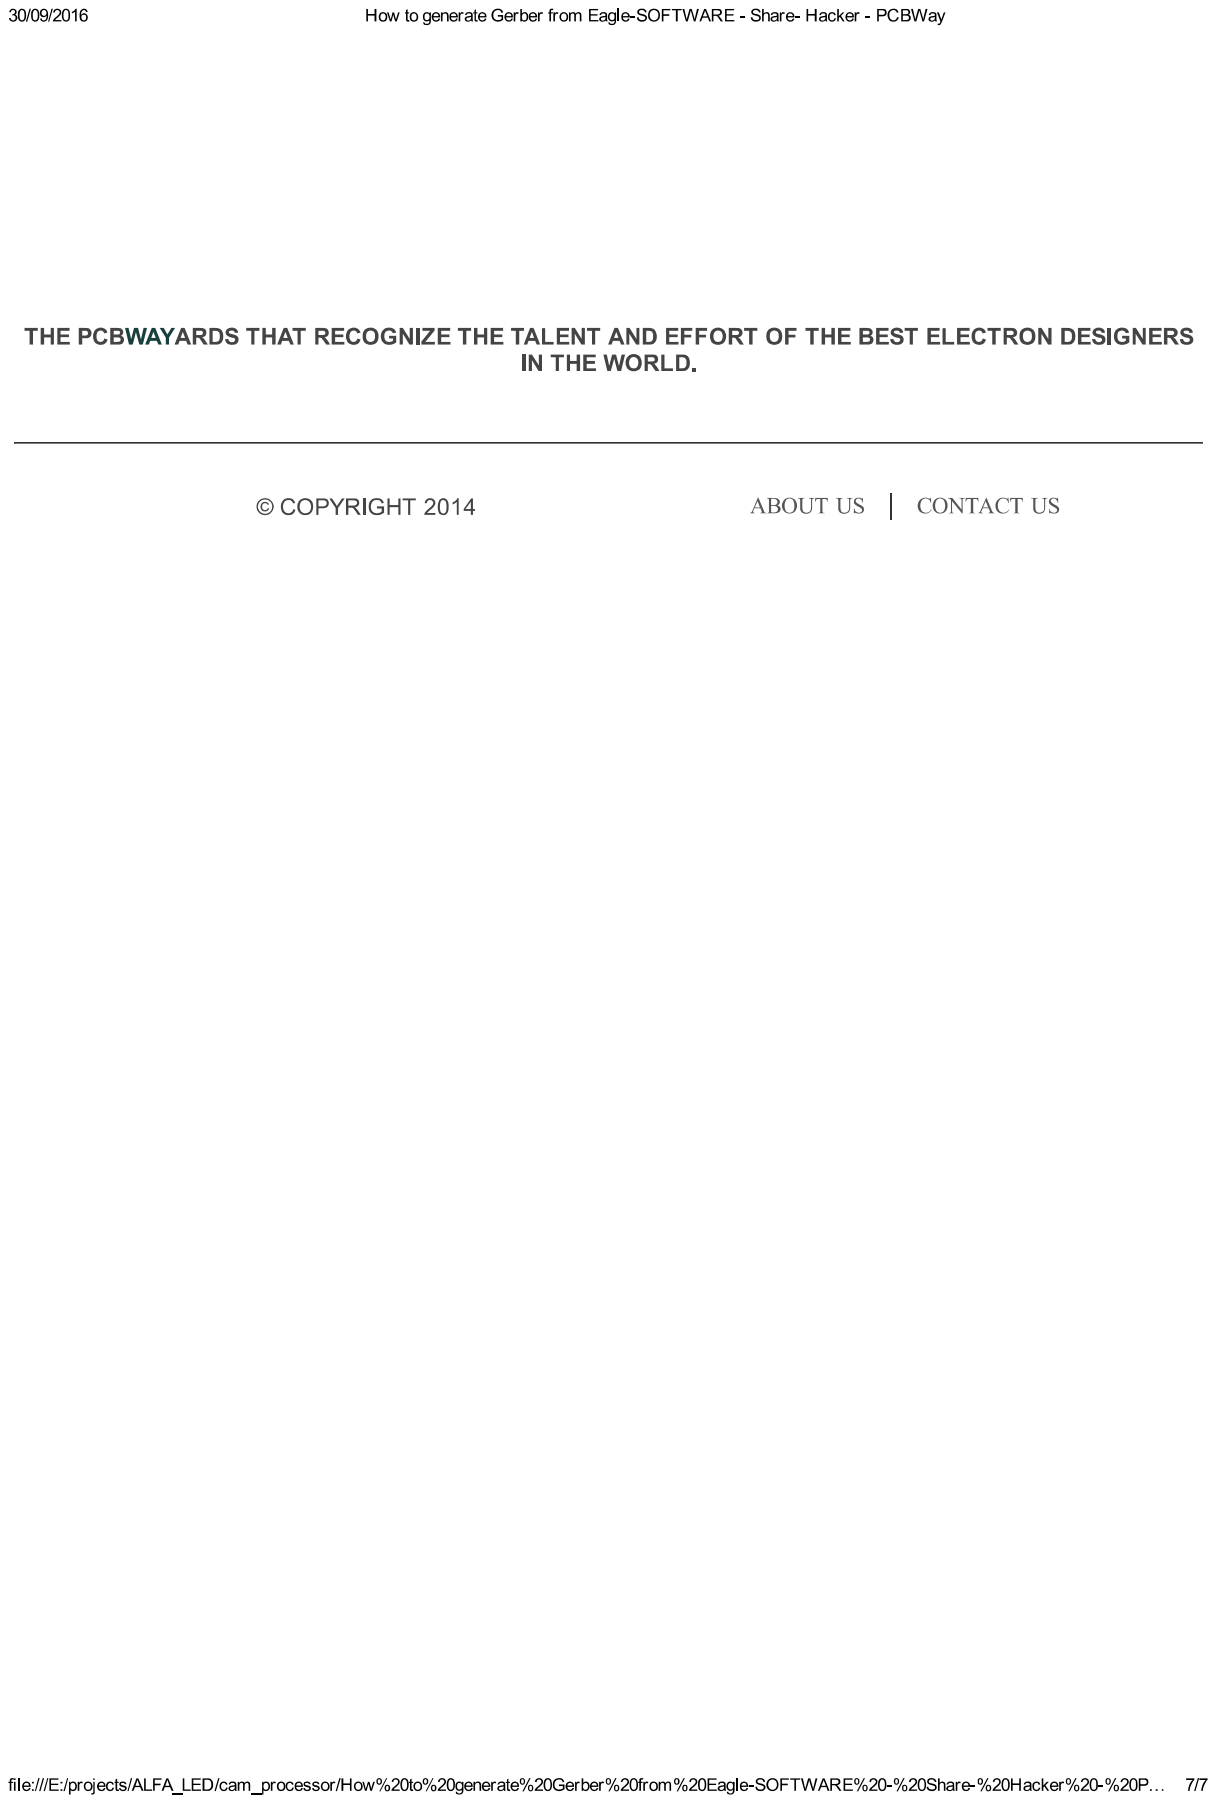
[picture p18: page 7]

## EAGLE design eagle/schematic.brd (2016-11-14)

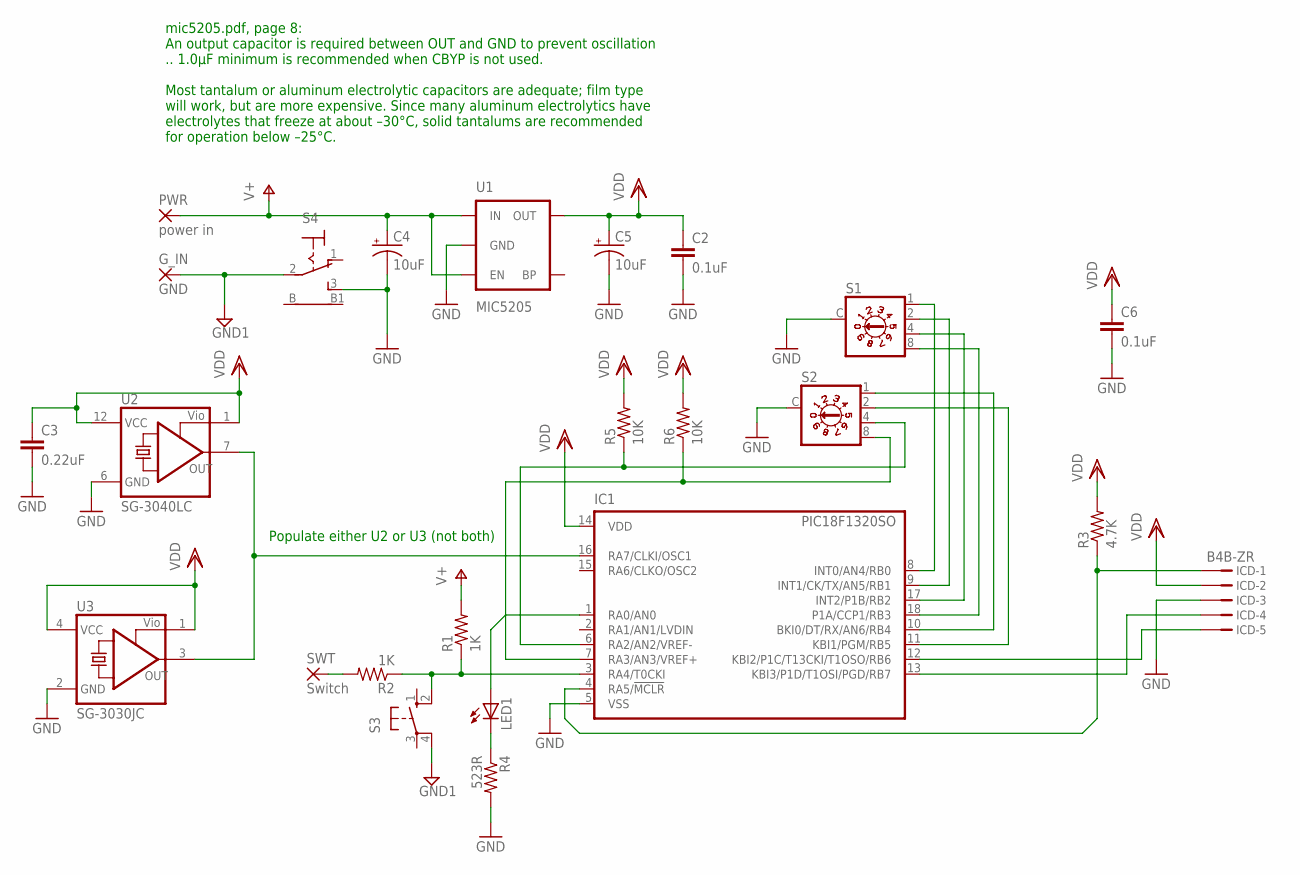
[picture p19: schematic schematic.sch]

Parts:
C2, C6: 0.1uF; C2.5-3
C3: 0.22uF; C2.5-3
C4, C5: 10uF; EIA3216
G_IN: GND; 2,15/1,0
IC1: PIC18F1320SO; SO-18W
ICD: B4B-ZR; B5B-EH
LED1: LED3MM
PWR: power in; 2,15/1,0
R1, R2: 1K; 0204V
R3: 4.7K; 0204V
R4: 523R; 0204V
R5, R6: 10K; 0204V
S1, S2: P101
S3: 10-XX; B3F-10XX
S4: C&K_E101; C&K_E101MD1ABE
SWT: Switch; 2,15/1,0
U1: MIC5205; SOT23-5
U2: SG-3040LC; SOJ-12-L
U3: SG-3030JC; JC_TYPE

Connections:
CLK: IC1.16 (RA7/CLKI/OSC1), U2.7 (OUT), U3.3 (OUT)
GND1: G_IN.1, S3.4 (P1), S4.2
unnamed: IC1.3 (RA4/T0CKI), R1.1, R2.1, S3.2 (S1)
unnamed: IC1.10 (BKI0/DT/RX/AN6/RB4), S2.1
unnamed: R2.2, SWT.1
unnamed: IC1.6 (RA2/AN2/VREF-), R5.1, S2.4
unnamed: IC1.7 (RA3/AN3/VREF+), R6.1, S2.8
unnamed: IC1.4 (RA5/!MCLR), ICD.1, R3.1
unnamed: IC1.13 (KBI3/P1D/T1OSI/PGD/RB7), ICD.4
unnamed: IC1.12 (KBI2/P1C/T13CKI/T1OSO/RB6), ICD.5
unnamed: IC1.11 (KBI1/PGM/RB5), S2.2
unnamed: IC1.1 (RA0/AN0), LED1.A
unnamed: LED1.K (C), R4.1
unnamed: C2.2, C3.2, C4.C (-), C5.C (-), C6.2, IC1.5 (VSS), ICD.3, R4.2, S1.C, S2.C, S4.3 (S), U1.2 (GND), U2.6 (GND), U3.2 (GND)
SWITCH_OUT_0: IC1.8 (INT0/AN4/RB0), S1.1
SWITCH_OUT_1: IC1.9 (INT1/CK/TX/AN5/RB1), S1.2
SWITCH_OUT_2: IC1.17 (INT2/P1B/RB2), S1.4
SWITCH_OUT_3: IC1.18 (P1A/CCP1/RB3), S1.8
V+: C4.A (+), PWR.1, R1.2, U1.1 (IN), U1.3 (EN)
VDD: C2.1, C3.1, C5.A (+), C6.1, IC1.14 (VDD), ICD.2, R3.2, R5.2, R6.2, U1.5 (OUT), U2.1 (VIO), U2.12 (VCC), U3.1 (VIO), U3.4 (VCC)

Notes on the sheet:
mic5205.pdf, page 8: An output capacitor is required between OUT and GND to prevent oscillation .. 1.0μF minimum is recommended when CBYP is not used. Most tantalum or aluminum electrolytic capacitors are adequate; film type will work, but are more expensive. Since many aluminum electrolytics have 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
Populate either U2 or U3 (not both)

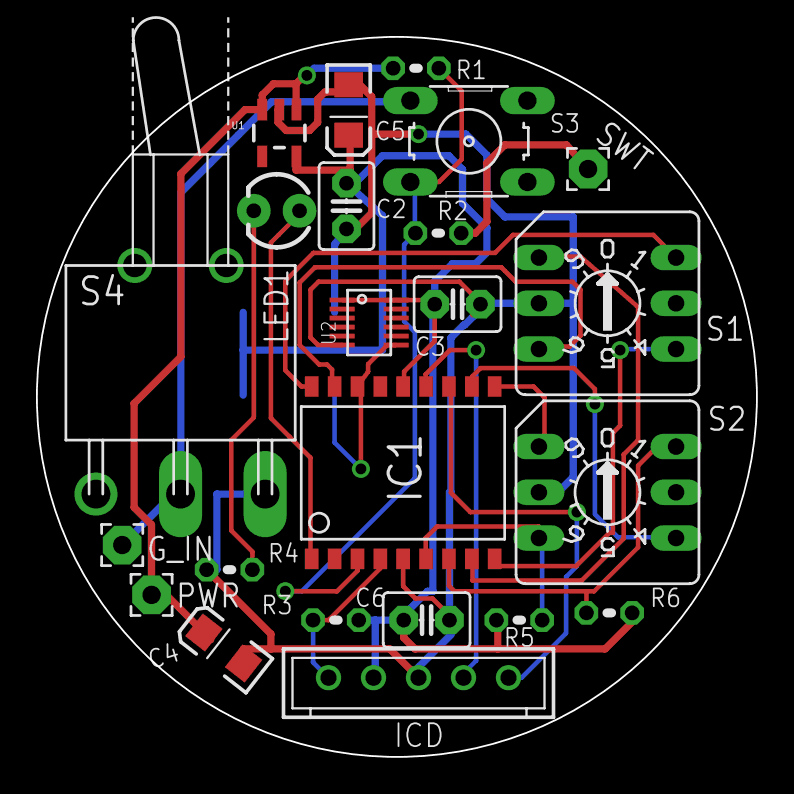
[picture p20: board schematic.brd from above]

Board: 2 copper layers, 40.0 x 40.0 mm, 24 parts (1 on the bottom side), 20 nets.

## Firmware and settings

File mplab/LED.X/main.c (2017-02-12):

/*
 * File:   main.c
 * Author: trev_
 *
 * Created on 11 September 2016, 13:12
 */

/******************************************************************************/
/* Files to Include                                                           */
/******************************************************************************/

#if defined(__XC)
    #include <xc.h>        /* XC8 General Include File */
#elif defined(HI_TECH_C)
    #include <htc.h>       /* HiTech General Include File */
#elif defined(__18CXX)
    #include <p18cxxx.h>   /* C18 General Include File */
#endif

#if defined(__XC) || defined(HI_TECH_C)

#include <stdint.h>        /* For uint8_t definition */
#include <stdbool.h>       /* For true/false definition */

#endif

#include "system.h"        /* System funct/params, like osc/peripheral config */
#include "wait.h"
#include "switches.h"

/******************************************************************************/
/* User Global Variable Declaration                                           */
/******************************************************************************/

/* i.e. uint8_t <variable_name>; */

/******************************************************************************/
/* Main Program                                                               */
/******************************************************************************/

// max delay = 99 x 15 minutes = 1485 minutes (0x05CD)
//           = 24.75 hours
//           = 89100 seconds (0x15C0C)
                     
void main(void) {
    unsigned int delay, i;
    
    led_configure();
    delay = read_switches();
    
    for (i = 0; i < 10; i++) {
        led_on();
        __delay_ms(50);
        led_off();
        __delay_ms(50);
    }
    
    wait(delay * 60 * 15);
    
    led_on();
    trigger_LAMP();
    while(1)
    { }
}

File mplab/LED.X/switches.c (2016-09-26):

/*
 * File:   switches.c
 * Author: trev_
 *
 * Created on September 11, 2016, 10:47 PM
 */

/******************************************************************************/
/*Files to Include                                                            */
/******************************************************************************/

#if defined(__XC)
    #include <xc.h>         /* XC8 General Include File */
#elif defined(HI_TECH_C)
    #include <htc.h>        /* HiTech General Include File */
#elif defined(__18CXX)
    #include <p18cxxx.h>    /* C18 General Include File */
#endif

#if defined(__XC) || defined(HI_TECH_C)

#include <stdint.h>         /* For uint8_t definition */
#include <stdbool.h>        /* For true/false definition */

#endif
#include "system.h"

#define SWITCH_1_BCD_1 PORTBbits.RB0 // pin also used by A/D channel 4 (AN4)
#define SWITCH_1_BCD_2 PORTBbits.RB1 // pin also used by A/D channel 5 (AN5)
#define SWITCH_1_BCD_4 PORTBbits.RB2 
#define SWITCH_1_BCD_8 PORTBbits.RB3

#define SWITCH_2_BCD_1 PORTBbits.RB4 // pin also used by A/D channel 6 (AN6)
#define SWITCH_2_BCD_2 PORTBbits.RB5
#define SWITCH_2_BCD_4 PORTAbits.RA2 // pin also used by A/D channel 2 (AN2)
#define SWITCH_2_BCD_8 PORTAbits.RA3 // pin also used by A/D channel 3 (AN3)

void configure_switches(void) {
    INTCON2bits.RBPU = 0; // Enable the port B pull ups
    
    // Disable A/D 
    ADCON1bits.PCFG2 = 1;
    ADCON1bits.PCFG3 = 1;
    ADCON1bits.PCFG4 = 1;
    ADCON1bits.PCFG5 = 1;
    ADCON1bits.PCFG6 = 1;
}

char inline convert_bcd_to_byte(char bit1, char bit2, char bit4, char bit8) {
    return bit1 + 
           bit2 * 2 +  
           bit4 * 4 + 
           bit8 * 8;
}

char read_switch1() {
    return convert_bcd_to_byte(!SWITCH_1_BCD_1, 
                               !SWITCH_1_BCD_2, 
                               !SWITCH_1_BCD_4, 
                               !SWITCH_1_BCD_8);
}

char read_switch2() {
    return convert_bcd_to_byte(!SWITCH_2_BCD_1, 
                               !SWITCH_2_BCD_2, 
                               !SWITCH_2_BCD_4, 
                               !SWITCH_2_BCD_8);
}

unsigned int read_switches(void) {
    configure_switches();
    return read_switch1() * 10 + 
           read_switch2();
}

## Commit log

2016-09-28 Replaced ICD board header with a JST-EH connector
    [schematic.brd, schematic.sch]
2016-09-28 using internal osc and timer2
2016-09-29 Timing using T2 and the external oscillator
    [main.c]
2016-09-29 T2 timer driven from internal oscillator (working)
    [main.c]
2016-09-30 T2 timer driven from external oscillator (working)
    [main.c]
2016-09-30 Added larger JC variant of oscillator to the underside of the PCB
    [Components.xlsx, schematic.brd, schematic.sch]
2016-09-30 Redo layout of extra oscillator
    [schematic.brd, schematic.sch]
2016-09-30 Add pdf's of schematic and PCB
2016-09-30 Created a new set of gerber files
    [schematic.GBL, schematic.GBO, schematic.GBS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]
2016-09-30 Files missing from the previous commit
    [schematic.brd, schematic.sch]
2016-10-30 Switch back to EC oscillator mode
2016-10-31 Added pdf specifying pcbway parameters
2016-10-31 Added aditional page to mechanical.vsd with external dimensions of case
2016-11-14 digiKey order 12Nov2016
    [Components.xlsx]
2016-11-14 Correct wiring of manual push switch, larger holes for ICD, increase U2 footprint
    [schematic.brd, schematic.sch]
2016-11-14 Create new set of gerber files
    [schematic.brd, schematic.sch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]
2016-12-03 Disable Fail-Safe Clock Monitor
    [Components.xlsx]
2016-12-11 Added Grunt task to export schematic and pcb images from Eagle
    [Components.xlsx, bill_of_materials.xlsx]
2016-12-12 More updates to the readme and some tidy of the C code
    [schematic.GBL, schematic.GBO, schematic.GBS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]
2016-12-12 Added 3D model of PCB
2016-12-18 WIP: Creating a 3D case using freeCad`
    [assembly.FCStd, case.FCStd, pcb_obj2.obj]
2016-12-18 Working on the top surface
    [case.FCStd]
2016-12-19 finished outerwall and topsurface
    [assembly.FCStd, case.FCStd]
2016-12-19 Added case.stl
    [case.stl]
2016-12-27 Finished top half of the case
    [assembly.FCStd, case.FCStd, case.step]
2017-01-01 First version of the case
    [assembly.FCStd, bottom.FCStd, case.FCStd]
2017-01-02 Files submitted to sculpteo
    [assembly.FCStd, bottom.FCStd, bottom.step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]
2017-02-12 Add links to the sculpteo models
    [bill_of_materials.xlsx]
